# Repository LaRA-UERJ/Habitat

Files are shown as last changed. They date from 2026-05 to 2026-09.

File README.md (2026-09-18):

# Habitat

Open hardware designs for adaptive workspaces, modular workstations and experimental infrastructure for robotics and automation labs.

Developed by [LaRA](https://github.com/LaRA-UERJ) — Laboratório de Robótica e Automação, UERJ.

## Status

**Exploring.** This repository collects ideas, concepts, and references as options — no definitive design decisions yet. We're building understanding before committing to solutions.

## Philosophy

We're interested in workspaces as living systems — environments that adapt to people, tasks, and workflows, not the other way around. Key inspirations:

- **Robert Propst** — *The Office: A Facility Based on Change* (1968): workspaces should reconfigure as work changes
- **Bürolandschaft** — organic layouts based on information flow, not grids
- **OpenStructures** — interoperable modular grid systems
- **Open Source Ecology** — labs that build their own infrastructure
- **Cedric Price / Fun Palace** — fully reconfigurable spaces, nothing fixed

See [docs/concepts.md](docs/concepts.md) for a full catalog of philosophies presented as options.

## Active Projects

| Project | Description | Status |
|---|---|---|
| [Soldering Bench](designs/soldering-bench/) | Mobile standing bench for PCB soldering with pegboard, soldering iron, hot air, casters | Brief phase |
| [Workstation 120°](designs/workstation-120/) | Standing computer station with pegboard-mounted monitor, whiteboard, 120° angle, casters | Brief phase |
| [Partition 120°](designs/partition-120/) | Mobile 3-panel folding partition, steel frame, upholstered panels, acoustic + visual privacy, casters | Brief phase |
| [Break Pod](designs/break-pod/) | Mobile coffee and break station with countertop, open shelving, two counter stools, optional lower cabinet, casters | Brief phase |
| [Focus Pod](designs/focus-pod/) | Mobile semi-enclosed microenvironment for deep focus, calls, and silent work, with retractable L-desk, lounge chair, acoustic panels, casters | Brief phase |

## Design Principles Catalog

We're evaluating (not adopting) principles from multiple sources. See [docs/design-principles-catalog.md](docs/design-principles-catalog.md).

Highlights:
- 120° angles instead of 90°
- Postural variation (sit/stand/lean)
- Vertical surfaces as mental extension (pegboard, whiteboard)
- Gradual privacy (not binary open/closed)
- Task differentiation (different bench for different work)
- Radical adaptability (casters, modular frames, reconfigurable in hours)

## Modular Arrangements

All Habitat modules share the **120° principle**. This is not just a geometric preference — it enables modules to join into closed polygons, creating collective environments from individual, mobile pieces.

A module's edges are cut at 60° (half the 120° vertex angle), so when two modules meet at a corner, they form a clean 120° joint. This means any arrangement of modules at 120° closes naturally into a polygon.

### Hexagonal Focus Bay (6 modules)

The primary arrangement. Six modules at 120° form a hexagon — a semi-enclosed collective focus environment:

```
          ┌─────────────┐
         ╱               ╲
        ╱    Partition    ╲        ← Closure panel (acoustic + visual)
       ╱                   ╲
      │                     │
      │   Workstation 120°  │     ← Individual CAD/programming station
      │                     │
      │                     │
      │   Workstation 120°  │     ← Individual CAD/programming station
       ╲                   ╱
        ╲   Partition      ╱      ← Closure panel
         ╲               ╱
      ────┘             └────      ← Entrance (open, or low partition)
```

**Hybrid composition:**
- 2–3 sides: individual workstations (Workstation 120°) facing inward
- 2 sides: closure panels (Partition 120°) for acoustic and visual privacy
- 1 side: open entrance, or a low module (Break Pod, half-partition)

**Properties:**
- Creates a shared focus zone without walls or construction
- Each person has their own station but shares the enclosed environment
- Fully reconfigurable — disassemble and rearrange in minutes
- Naturally absorbs the 120° angle of each module — no custom joints needed
- Complementary to the Focus Pod: this is collective, the pod is individual

### Pentagon (5 modules, 108°)

Fewer modules, but requires module edges cut at 54° instead of 60° — a different geometry that doesn't align with the 120° principle. Explored as a concept (see reference images) but not the primary direction.

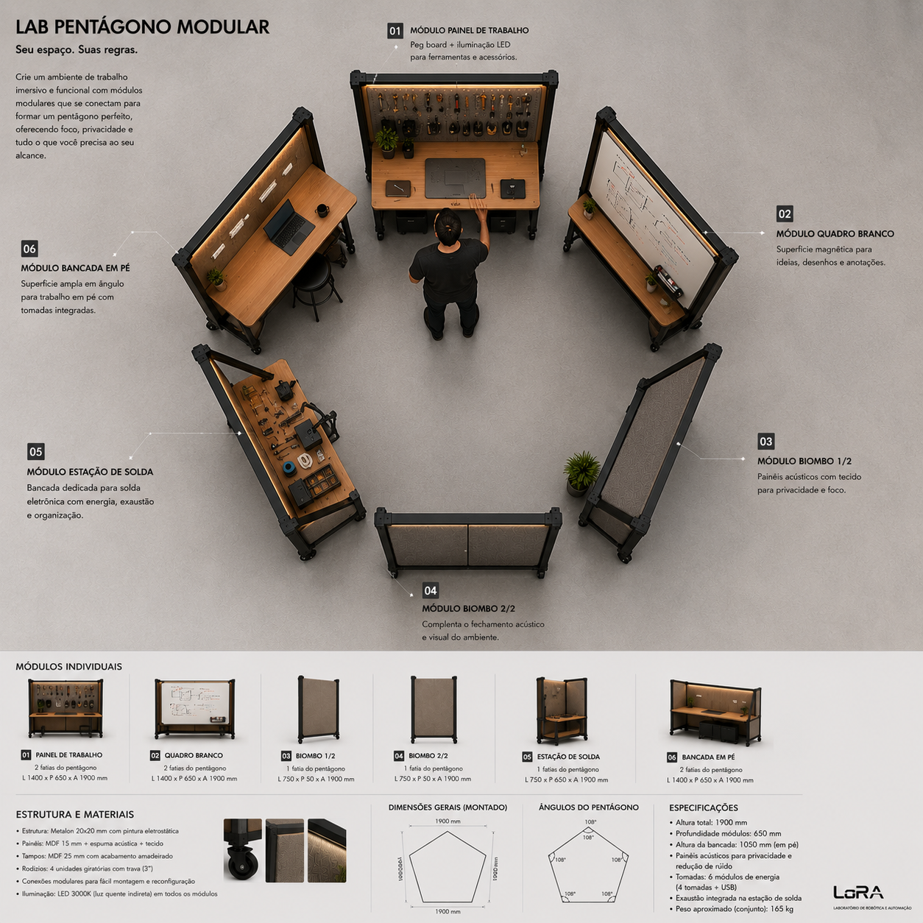
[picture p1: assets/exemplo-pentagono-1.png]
Pentagon arrangement concept 1


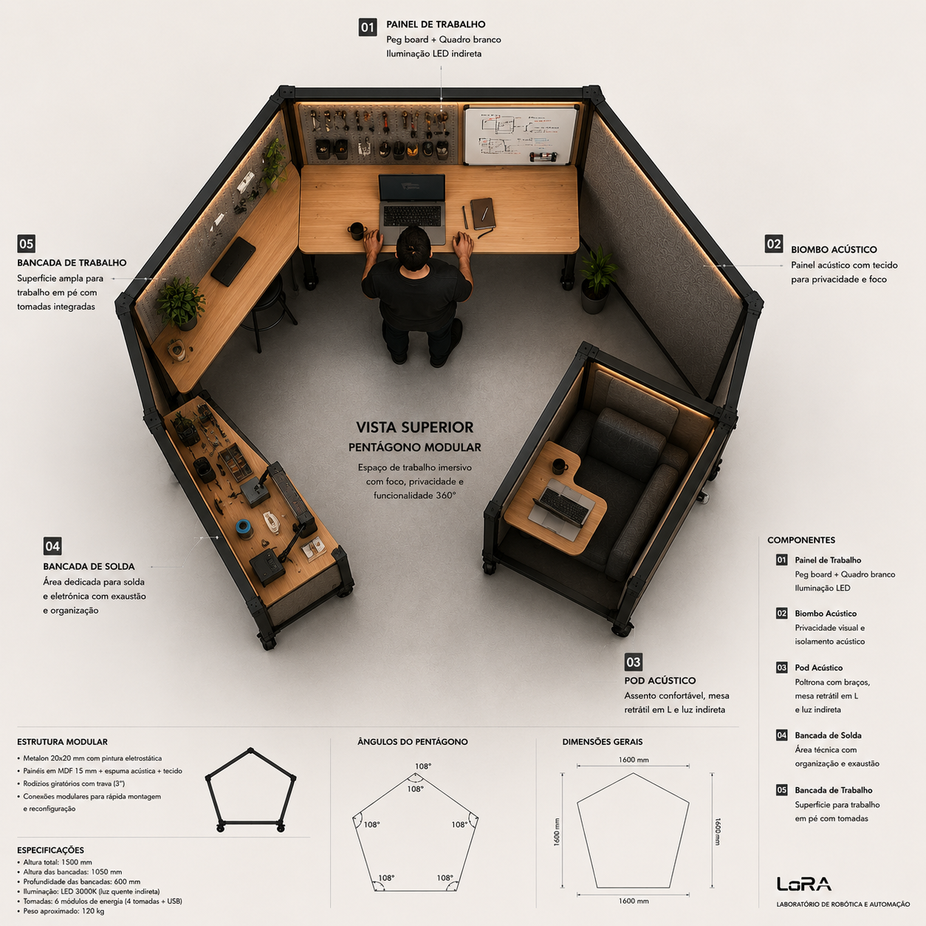
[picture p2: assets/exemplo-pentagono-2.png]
Pentagon arrangement concept 2


*Reference images illustrating the polygon arrangement concept. The images show pentagonal arrangements (108°) — the adopted direction is hexagonal (120°) to maintain alignment with the project's core geometry.*

### Module Roles in Arrangements

| Module | Role in Polygon | Notes |
|---|---|---|
| Workstation 120° | Active work side | Individual station facing inward |
| Partition 120° | Closure side | Acoustic + visual privacy |
| Break Pod | Entrance / social side | Low height, invites approach |
| Focus Pod | **Not part of arrangements** | Individual, separate, standalone |

### Implications for Module Design

For modules to join into polygons, each module needs:
- **Square-cut or 60°-cut edges** on the joining sides (exact approach TBD)
- **Consistent frame height** at the joint line so panels align
- **No protruding elements** (handles, casters, brackets) at the joint edges
- **Optional mechanical connection** — clips, magnets, or brackets to hold modules together

See [docs/layout-ideas.md](docs/layout-ideas.md) for detailed layout analysis.

**[Interactive Polygon Explorer →](https://lara-uerj.github.io/Habitat/tools/polygon-explorer.html)** — Adjust polygon, module size, bench depth, gaps, and person dimensions to visualize arrangements in scale.

## Layout Ideas

See [docs/layout-ideas.md](docs/layout-ideas.md) for spatial organization concepts, including a proposed layout for the LaRA 7×7m lab.

## References

All collected visual references, open-source projects, books, and videos: [docs/references.md](docs/references.md).

## Working in this repository

The CAD for the modules is generated by script, headless (FreeCAD + reportlab), not by
hand in a GUI. See:

- [AGENTS.md](AGENTS.md) — how to work here, house rules and module status
- [docs/cad-workflow.md](docs/cad-workflow.md) — the drawing pipeline and its pitfalls

## License

Hardware designs: **CERN-OHL-S v2** (Strongly Reciprocal) — see [LICENSE](LICENSE).

Documentation and text: **CC BY-SA 4.0**.

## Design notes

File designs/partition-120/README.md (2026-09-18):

# Partition 120°

Mobile 3-panel folding partition with upholstered panels for acoustic separation and visual privacy in the lab.

---

## Brief

A free-standing folding screen (biombo) with three panels joined at 120° angles. Steel frame (metalón) with locking casters, upholstered panels (wood + foam + fabric) for sound absorption. Designed to create semi-enclosed zones in the 7×7m LaRA lab — separating noisy tasks (mechanical, CNC) from quiet tasks (CAD, reading) while maintaining visual permeability and reconfigurability.

---

## Requirements

- **3 panels, 2 folds at 120°** — Each adjacent pair meets at 120°, forming a gentle arc (~240° total sweep) that partially encloses without closing off
- **Steel frame (metalón)** — Square tubing (likely 25×25 or 30×30), welded or bolted, painted matte black
- **Locking casters on feet** — Mobile by design; brakes engaged when positioned
- **Upholstered panels** — Plywood or MDF base + acoustic foam + fabric covering, attached to frame
- **Dual function** — Acoustic damping (reduces noise transfer between lab zones) + visual privacy (creates focus areas without full walls)
- **Foldable for storage** — Panels fold flat when not in use

---

## Design Options (Not Decided)

1. **Welded steel frame + piano hinges** — Continuous hinge along the full height of each joint. Strong, simple. Pros: rigid, clean. Cons: non-disassemblable, hinge must be sized for 120° stop.

2. **Bolted steel frame + pin hinges** — Frame members bolted together with removable pin hinges at the joints. Pros: disassembles for transport/storage. Cons: more hardware, potential play at joints.

3. **Aluminum extrusion frame (4040 profile)** — Modular, T-slot accessories, no welding needed. Pros: infinitely adjustable, lab can modify later. Cons: significantly more expensive than welded steel.

---

## Dimensions

Brief ranges, with what the CAD has settled so far. See [`cad/README.md`](cad/README.md)
for the full parameter table and the open decisions.

| Dimension | Brief range | Settled in CAD | Notes |
|---|---|---|---|
| Panel width | 80–100 cm | **900 mm** | Each of the 3 panels |
| Total height | 150–180 cm | **1706 mm** (1600 frame + 102 caster + 4 base plate) | Com o rodízio comercial de 102 mm |
| Panel thickness | 5–8 cm | **15 mm plywood** (foam + fabric open) | Cad passo 2: placa de compensado decorada; a espuma (30–50 mm) e o tecido seguem em aberto e não são desenhados |
| Frame tube | 25×25 or 30×30 mm | **30×30×1,5 mm** | Metalon quadrado — see Steel Frame Specs below |
| Caster diameter | 50–75 mm | **75 mm**, with brake | **4 units**, 2 per panel, only on the outer panels, inset 100 mm inside the panel plane |
| Base plate | — | **100 × 70 × 4 mm** welded under the bottom rail | 4 oblong slots 25 × 9 mm for the caster bolts |

Derived from the CAD: passo 1 (estrutura) 1358 × 1561 mm de planta, 14,64 m de tubo,
19,65 kg de aço. Passo 1b (base decidida): envoltória 1357,5 × 1560,9 × 1706 mm, 14,64 m de
tubo, 19,65 kg de tubo + 0,88 kg de chapas, 4 rodízios, margem de tombamento de 179,9 mm
(tomba a 11,62°; com 6 rodízios era 16,7°). Passo 2 (placa de compensado decorado, aprovado):
placa de 834 × 1534 × 15 mm com 3,0 mm de folga ao tubo, 12 cantoneiras 25 × 25 × 3 soldadas de
face e 12 parafusos de madeira Ø4 × 16, **55,32 kg** fabricados no total, painel de 11,51 kg por
folha, 13,8 kg por rodízio (limite 70 kg) e margem de tombamento de **175,0 mm (11,07°)**.

---

## Upholstered Panel Construction

| Layer | Material | Notes |
|---|---|---|
| Base | **Compensado decorado 15 mm**, 834 × 1534 mm | Decidido no CAD passo 2: 3 mm de folga ao tubo em todo o contorno |
| Foam | Espuma acústica 30–50 mm densidade média | **Em aberto** — não modelada nem desenhada |
| Fabric | Tecido acústico ou veludo | **Em aberto** — idem |
| Attachment | **12 cantoneiras em L 25 × 25 × 3 mm, soldadas de face na face interna dos montantes** (perna A 22,5 × 25 mm) + 4 parafusos de madeira Ø4 × 16 por folha, com a perna B deitada sobre a placa e o furo piloto Ø2,5 | O parafuso só é acionável na direção da normal do painel — é isso que decide a geometria da cantoneira. Ordem: soldar as abas, parafusar a placa nua, e só então colar espuma e grampear tecido |

---

## Steel Frame Specs

Espessuras de metalon típicas para mobiliário (dados de mercado):

| Aplicação | Bitola (gauge) | Espessura | Uso |
|---|---|---|---|
| Leve / budget | 18–22 ga | 0,75–1,2 mm | Móveis baratos, arquivos |
| Intermediário | 16 ga | ~1,5 mm | Mesas de escritório, móveis comerciais |
| Profissional / pesado | 14 ga | ~2,0 mm | Standing desks, setups multi-monitor |
| Industrial | 12 ga | ~2,65 mm | Bancadas pesadas, frames estruturais |

### Recomendação para o biombo

O biombo é alto (~160 cm), estreito, com painéis estofados — precisa de rigidez mas não suporta cargas pesadas como uma mesa.

| Componente | Espessura recomendada | Tubo | Racional |
|---|---|---|---|
| Colunas verticais | **1,5 mm (16 ga)** | 25×25 ou 30×30 mm | Suficiente para rigidez sem excesso de peso |
| Travessas horizontais | 1,2–1,5 mm | 25×25 mm | Menos solicitação que as colunas |
| Base / pés | 1,5–2,0 mm | 30×30 mm | Área de impacto (rodízios, batidas) |

**Sweet spot:** tubo 30×30 com 1,5 mm — leve para mover, rígido o suficiente para não balançar. Para mais robustez: 30×30 com 2,0 mm (14 ga).

### Fontes

- Eureka Ergonomic: "Steel Gauge Guide" — https://eurekaergonomic.com/blogs/eureka-ergonomic-blog/steel-gauge-guide-gaming-desk-frame-thickness
- Jianglin Steel: "Steel Tube for Furniture" — https://jlinsteel.com/steel-tube-for-furniture
- Prolamsa USA: Furniture tubing specs — https://www.prolamsausa.com/furniture/

---

## Hinge / Joint Design

The 120° angle between panels needs hinges that either:
- **Stop at 120°** — Hinge with built-in stop (custom bracket or welding limit)
- **Allow 120° but can fold flat** — Hinge permits 0°–180° range; position held by a detent, chain, or magnetic catch

Options:
- Dobradiça de piano (full-length) com batente soldado a 120°
- Dobradiça com pino removível (parafuso ou pino quick-release)
- Articulação tipo livro com limitador angular

---

## Reference Image

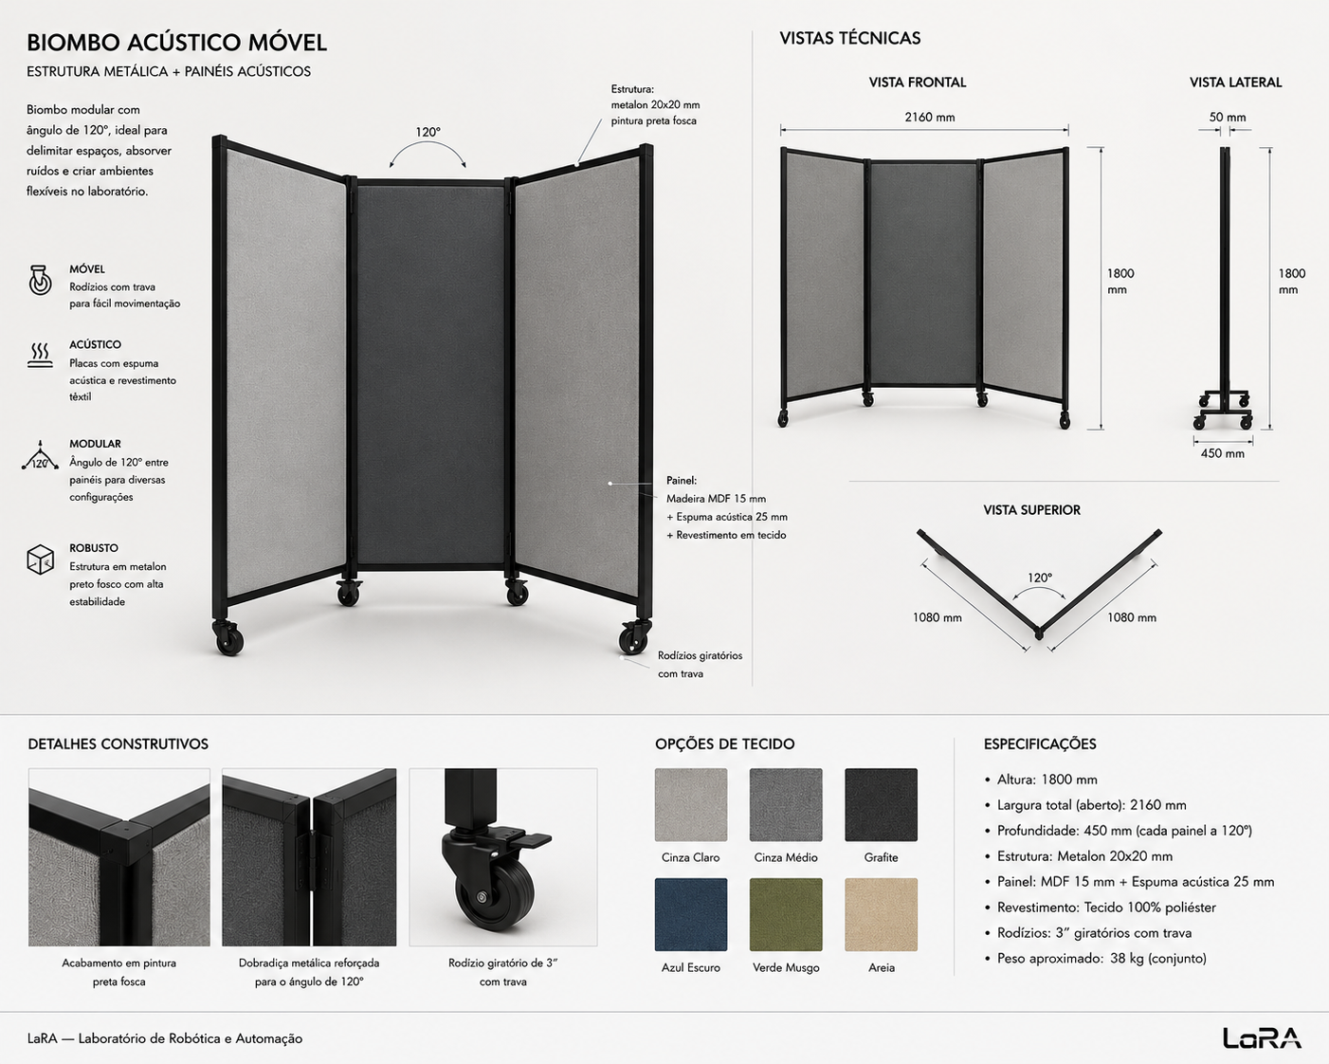
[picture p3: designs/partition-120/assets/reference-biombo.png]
Biombo reference — metal frame, upholstered panels, casters, 120° angles


*Three-panel folding partition: black metalón frame, locking casters, upholstered panels with wood + foam + fabric, 120° between panels.*

---

## Principles Being Evaluated

- [120° instead of 90°](../../docs/design-principles-catalog.md#120-instead-of-90) — Core geometry; avoids harsh corners and dead spaces
- [Gradual privacy](../../docs/design-principles-catalog.md#gradual-privacy-not-binary) — Medium privacy zone: blocks direct sightlines but preserves peripheral awareness
- [Everything on casters](../../docs/design-principles-catalog.md#everything-on-casters) — Mobile partitions reconfigure the lab in minutes
- [Noise gradient](../../docs/design-principles-catalog.md#noise-gradient) — Acoustic panels support the noise separation strategy between lab zones
- [Task differentiation](../../docs/concepts.md#1-robert-propst--the-office-a-facility-based-on-change-1968) — Partitions help define distinct activity zones within the same room

---

## Open Questions

- **Tecido:** qual material? Veludo acústico, camurça, lona? Precisa ser lavável e resistente em lab com 30+ estudantes
- **Dobradiças:** tipo piano contínua ou pino removível? Precisa de batente a 120° ou liberdade total?
- **Base:** resolvido — 4 rodízios, 2 por folha, só nas folhas das pontas, recuados 100 mm
  dentro do plano da folha (o pé em L foi descartado: risco de tropeço no lab)
- **Estabilidade / anti-capotamento:** resolvido — sem base alargada. Medido no modelo do passo
  2, com o painel dentro do CG: margem de tombamento de 175,0 mm (11,07°) com 4 rodízios; era
  179,9 mm (11,62°) sem o painel e 16,7° com 6 rodízios
- **Empilhável:** quando dobrado, pode ficar em pé encostado na parede? Precisa de suporte?
- **Acústica real:** quanta absorção o painel estofado realmente proporciona? Precisa de_teste ou dados de NRC (Noise Reduction Coefficient)?
- **Integração com bancadas:** o biombo pode servir como extensão da bancada de solda ou workstation 120°? Encaixa no sistema modular?
- **Cor do tecido:** escura (menos suja) ou clara (mais leve visualmente)? Padronizar ou permitir variação?
- **Painel de um lado só ou dos dois?** Estofado nos dois lados ou só no lado interno (lado do "fechamento")?
- **Peso total:** resolvido em parte — 55,32 kg medidos no CAD do passo 2 (tubo 19,652 +
  placa 34,543 + chapas 0,766 + cantoneiras 0,332 + parafusos 0,026), ainda sem o acabamento
  (espuma + tecido). Carga por rodízio 13,8 kg, contra limite de 70 kg/un

---

## CAD

Passo 1 (estrutura de metal) e passo 1b (base decidida: 4 rodízios comerciais), gerados por
script headless. Ver [`cad/README.md`](cad/README.md) para regenerar e para as pendências.

| Artefato | O que é |
|---|---|
| [`cad/saida/passo1_prancha.pdf`](cad/saida/passo1_prancha.pdf) | Prancha A3 cotada do passo 1 — estrutura |
| `cad/saida/passo1_biombo.step` | Sólido do passo 1 — **não versionado** (regenere com o script) |
| [`cad/saida/passo1_lista_corte.csv`](cad/saida/passo1_lista_corte.csv) | Lista de corte do passo 1 |
| [`cad/saida/passo1b_prancha.pdf`](cad/saida/passo1b_prancha.pdf) | **Prancha A3 do passo 1b** — frente perpendicular à folha central, lateral paralela às folhas das pontas, planta, isométrica e detalhe da base em 1:2 |
| `cad/saida/passo1b_prancha.dxf` | Geometria em mm para CAD — **não versionado** (regenere com o script) |
| `cad/saida/passo1b_biombo.step` | Sólido do passo 1b — **não versionado** (regenere com o script) |
| [`cad/saida/passo1b_lista_corte.csv`](cad/saida/passo1b_lista_corte.csv) | Lista de corte: tubo, chapa e rodízio |
| [`cad/saida/passo1b_render_iso.png`](cad/saida/passo1b_render_iso.png) | Render 3D isométrico |
| [`cad/saida/passo1b_render_persp.png`](cad/saida/passo1b_render_persp.png) | Render 3D em perspectiva |
| [`cad/saida/passo1b_render_close.png`](cad/saida/passo1b_render_close.png) | Render 3D do close na base |
| [`cad/saida/passo2_prancha.pdf`](cad/saida/passo2_prancha.pdf) | **Prancha A3 do passo 2** — 4 vistas em cima; embaixo a placa decorada 1:20, a lista de material e as notas de fixação e montagem |
| `cad/saida/passo2_prancha.dxf` / `passo2_biombo.step` | Geometria em mm e sólido do passo 2 (67 peças) — **não versionados** |
| [`cad/saida/passo2_lista_corte.csv`](cad/saida/passo2_lista_corte.csv) | Lista de corte: tubo, chapa, cantoneiras e placa |
| [`cad/saida/passo2_lista_compras.csv`](cad/saida/passo2_lista_compras.csv) | Lista de compras: compensado, parafusos e o acabamento opcional |
| [`cad/saida/passo2_render_iso.png`](cad/saida/passo2_render_iso.png) | Render 3D isométrico do conjunto com o painel |
| [`cad/saida/passo2_render_persp.png`](cad/saida/passo2_render_persp.png) | Render 3D em perspectiva |
| [`cad/saida/passo2_render_close.png`](cad/saida/passo2_render_close.png) | Render 3D do close em **uma fixação** (cantoneira + parafuso + placa) |

O que já está fechado: metalon 30×30×1,5 mm, folha de 900 × 1600 mm, 120° internos entre
folhas (giro de 60° por junta), rodízio moveleiro Ø75 com freio de altura 102 mm e carga
70 kg, **4 rodízios** (2 por folha, só nas folhas das pontas, recuados 100 mm dentro do plano
da folha), chapa soldada 100 × 70 × 4 mm com 4 rasgos oblongos sob cada rodízio, altura total
1706 mm, 14,64 m de tubo e, no passo 2, **placa de compensado decorada 15 mm de 834 × 1534 mm**
com 3 mm de folga ao tubo, fixada por **12 cantoneiras 25 × 25 × 3 mm soldadas de face** na face
interna dos montantes com parafuso de madeira Ø4 × 16 (furo piloto Ø2,5). Massa fabricada
55,32 kg e margem de tombamento 175,0 mm (11,07°).

O que ainda não existe: o acabamento do painel (espuma e tecido — como e se existem), as
dobradiças, e a confirmação do passo entre os furos da chapa (medir o rodízio comprado antes
de furar). Ver [`cad/README.md`](cad/README.md#pendências).

## Files

| Path | Description |
|---|---|
| `cad/` | Script de geração + `saida/` com prancha, lista de corte, relatório e renders (DXF/STEP saem do script, não versionados) |
| `assets/reference-biombo.png` | Reference image of the partition concept |

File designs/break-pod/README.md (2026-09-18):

# Break Pod

Mobile coffee and break module for shared lab spaces. A compact, self-contained station that provides a ritual pause point — coffee, conversation, and informal collaboration — without requiring permanent infrastructure or plumbing.

---

## Brief

A free-standing, mobile break station inspired by coffee carts, kitchen islands, and micro-bars. The concept combines a countertop for a coffee machine, open shelving for cups and supplies, optional lower cabinet storage, and two stools — all on locking casters for reconfigurable lab architecture. The break pod is not just about coffee; it's about creating a intentional pause point in the workspace, a social node that encourages informal exchange and mental reset.

### Use Cases

- Coffee and tea preparation
- Informal conversations and quick syncs
- Mental reset between deep work sessions
- Hosting visitors with a coffee
- Water cooler moments in a lab context
- Snack and refreshment station

### Sensation

The pod should transmit:

- Warmth
- Informality
- Hospitality
- Shared ownership
- Pause / respite

A "casulo de pausa" — a coffee break cockpit, a social anchor in the lab.

---

## Requirements

- **Countertop surface** — Dedicated space for a coffee machine (espresso, drip, or pod-based), with enough depth for the machine + cups + preparation area
- **Open shelving** — At least one shelf above or behind the counter for cups, coffee, sugar, tea, and supplies. Visible and accessible — the supplies are part of the aesthetic, not hidden away
- **Two stools** — Compact counter-height stools (or stools that store under/around the pod) for sitting and chatting
- **Mobile (locking casters)** — Industrial black swivel casters with brakes. Same mobility language as the other pods
- **Optional lower cabinet** — Enclosed storage below the counter for bulk supplies, cleaning, waste bin. To be decided if included or kept minimal
- **Industrial clean aesthetic** — Consistent with the lab language: black matte steel frame, warm wood or laminate countertop, minimal hardware

---

## Design Options (Not Decided)

### Chassis

1. **Welded metalon frame** — 30×30 mm steel tubing, welded joints. Maximum rigidity, cleanest look. Non-disassemblable.
2. **Bolted metalon frame** — 30×30 mm tubing with bolted corner brackets. Disassembles for transport, no welding needed.
3. **Mixed frame (20×20 + 30×30)** — 30×30 for columns and base, 20×20 for shelf frames and secondary structure. Weight savings where possible.

### Lower Storage

1. **Open shelf** — Simple lower shelf, fully visible. Minimal, light, easy to build. No doors or drawers.
2. **Enclosed cabinet** — Doors (MDF or plywood) with magnetic catches. Hides clutter, stores bulk supplies and waste bin.
3. **Hybrid** — One side open shelf, one side cabinet. Best of both but more complex.
4. **No lower storage** — Countertop and upper shelf only, maximum visual lightness. Supplies stored elsewhere.

### Countertop

1. **Solid wood (hardwood)** — Warm, tactile, ages beautifully. Requires finishing (oil or varnish). Heavier.
2. **Plywood with hardwood edge** — Birch or pine plywood, exposed edge banding. Lab aesthetic, lighter, cheaper.
3. **Laminate (Formica)** — Durable, waterproof, easy to clean. Less character, more practical.
4. **Stainless steel** — Industrial kitchen aesthetic, ultra-durable, waterproof. Cold aesthetic but very practical for spills.

### Shelving

1. **Upper open shelf (fixed)** — Single shelf above/behind the counter. Simple, permanent.
2. **Multiple narrow shelves** — Stacked shelves at different heights for cups, supplies, decoration.
3. **Pegboard back panel** — Metalon + pegboard or slatwall behind counter. Hooks for cups, accessories. Consistent with other lab projects.
4. **Side shelf / wing** — Additional narrow surface extending to one side, for extra prep space or decoration.

---

## Dimensions (TBD)

| Dimension | Range | Notes |
|---|---|---|
| Overall width | 100–130 cm | Machine + shelf + prep area + stool clearance on sides |
| Overall depth | 50–65 cm | Counter depth, enough for machine + cups in front |
| Overall height | 90–110 cm | Counter height (~90 cm) + upper shelf or backsplash |
| Counter height | ~90 cm | Standard counter / bar height |
| Counter depth | ~50–60 cm | Machine depth + cup space |
| Upper shelf height | ~15–25 cm above counter | Accessible, not too high |
| Stool seat height | ~65 cm | Counter-height stool |

---

## Steel Frame Specs

| Component | Recommended | Tube | Rationale |
|---|---|---|---|
| Main columns | 1,5–2,0 mm | 30×30 mm | Primary structural members, support counter + machine + supplies |
| Base frame | 1,5–2,0 mm | 30×30 mm | Caster mounting points, stability base |
| Shelf frames | 1,0–1,5 mm | 20×20 mm | Lighter secondary structure for shelving |
| Counter support | 1,5 mm | 30×30 mm | Supports countertop + dynamic load (machine + water) |

**Finish:** Pintura eletrostática preta fosca microtexturizada (consistent with other pods)

---

## Stools

| Feature | Spec |
|---|---|
| Quantity | 2 |
| Style | Compact counter stool, industrial or minimalist |
| Seat height | ~65 cm |
| Material | Steel frame + wood seat, or all-steel |
| Storage | Can tuck against or under the pod when not in use |
| Integration | To be decided — integrated into frame or freestanding |

---

## Mobility

| Feature | Spec |
|---|---|
| Caster type | Industrial, black, swivel, with brake |
| Quantity | 4 (one per corner of base frame) |
| Diameter | 50–75 mm |
| Purpose | Pod moves to where it's needed — near workstations, in a corner, or against a wall |

---

## Optional Extras

### Water & Waste

- Galão de água embutido (5–10L) — gravity-fed or small pump
- Sistema de água ligado à rede (se posição fixa)
- Coletor de gotejamento / drip tray
- Lixeira embutida no armário inferior

### Electrical

- Tomada AC para máquina de café (110/220V)
- USB-C PD charging para celular enquanto toma café
- Iluminação indireta sob a prateleira (LED warm, 2700–3000K)

### Social

- Quadro negro / chalkboard em um dos lados para recados e mensagens
- Suporte para planta ou decoração
- Hook para aventais ou toalhas

---

## Reference Image

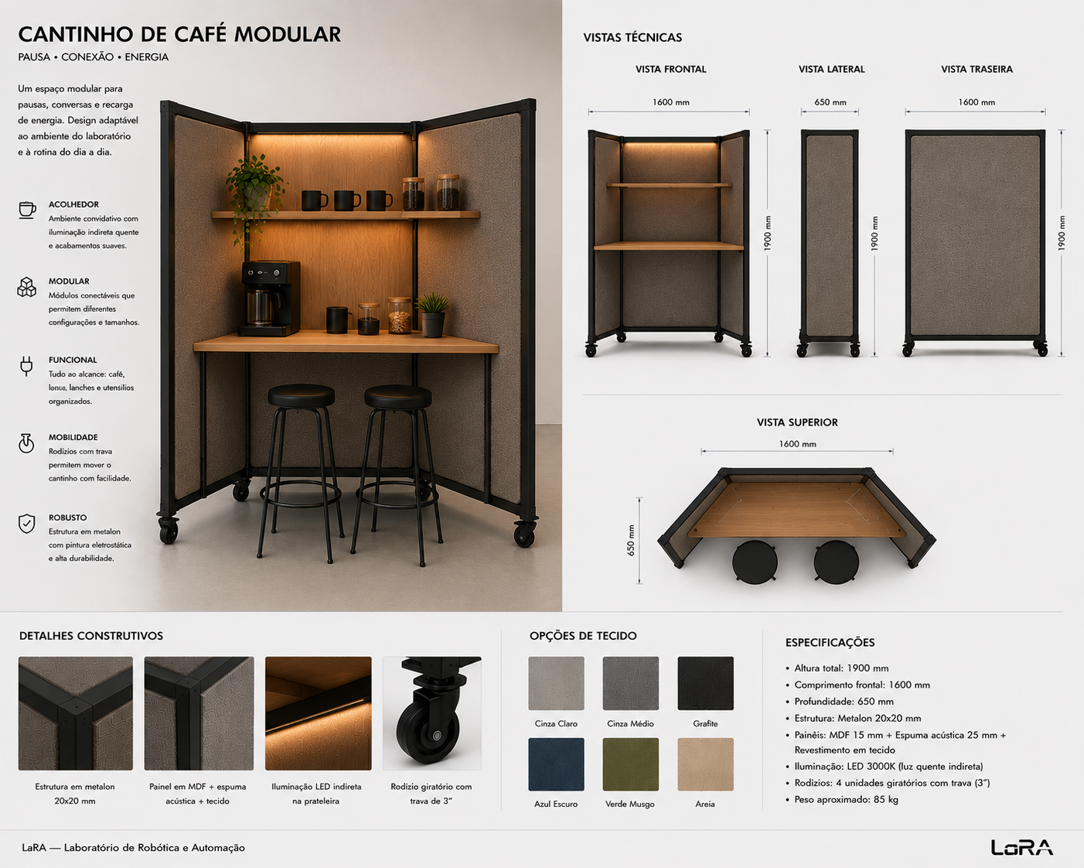
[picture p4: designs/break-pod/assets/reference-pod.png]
Break Pod reference — mobile coffee station with countertop, shelving, and stools


*Mobile break/coffee module with countertop for coffee machine, open shelving, two counter stools, and industrial casters.*

---

## Principles Being Evaluated

- [Everything on casters](../../docs/design-principles-catalog.md#everything-on-casters) — Mobile social infrastructure, reconfigurable in minutes
- [Task differentiation](../../docs/concepts.md#1-robert-propst--the-office-a-facility-based-on-change-1968) — A dedicated station for breaks, distinct from work zones
- [Walls as mental extension](../../docs/design-principles-catalog.md#walls-as-mental-extension) — Shelving and pegboard display supplies as part of the aesthetic
- [Gradual privacy](../../docs/design-principles-catalog.md#gradual-privacy-not-binary) — Semi-open, social posture — the opposite of the Focus Pod, a complementary social node
- [Postural variation](../../docs/design-principles-catalog.md#postural-variation) — Standing at counter + perched on stools — a break from seated work

---

## Name Candidates

Working names within the LaRA universe:

- **LaRA Break Pod**
- **LaRA Coffee Pod**
- **LaRA Brew Cart**
- **LaRA Pause Station**
- **LaRA Social Node**
- **LaRA Café Module**
- **LaRA Refuel Pod**

---

## Open Questions

- **Lower cabinet:** Enclosed storage, open shelf, or nothing at all?
- **Coffee machine:** Specific machine in mind? Dimensions and power requirements affect the design
- **Water supply:** Gravity-fed galão, plumbed, or manual fill?
- **Waste:** Integrated bin or separate?
- **Stools:** Integrated into frame or freestanding? Fixed or foldable?
- **Width:** Minimum viable width that feels comfortable for two people?
- **Countertop material:** Wood (warm) vs laminate (practical) vs steel (industrial)?
- **Pegboard:** Worth adding for cup hooks and accessory display?
- **Integration with other projects:** Share casters, frame joints, panel construction with Focus Pod and Partition 120°?
- **Position in lab:** Against wall or freestanding? Affects back panel design
- **Supplies capacity:** How many cups, how much coffee? Determines shelf sizing

---

## Files

| Path | Description |
|---|---|
| `cad/` | CAD files (.step, .FCStd) — to be added |
| `assets/reference-pod.png` | Reference image of the break pod concept |

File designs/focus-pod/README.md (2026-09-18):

# Focus Pod

Mobile microenvironment for deep focus, calls, reading, and silent work. A semi-enclosed capsule that provides psychological comfort, partial isolation, and an industrial-lab aesthetic — without feeling like a corporate booth.

---

## Brief

A free-standing, mobile individual pod inspired by acoustic pods, reading nooks, Scandinavian booths, and micro-architecture. The concept combines comfort, acoustic damping, indirect lighting, a retractable L-shaped desk, and an integrated lounge chair — all on locking casters for reconfigurable lab architecture.

### Use Cases

- Deep coding / programming
- Video calls and meetings
- Reading datasheets and papers
- Quick rest / mental reset
- Brainstorming and sketching
- Silent concentrated work
- Personal retreat in a shared lab

### Sensation

The pod should transmit:

- Security
- Concentration
- Warmth
- Silence
- Introspection

Almost a "casulo de engenharia" — a human cockpit, a focus capsule.

---

## Requirements

- **Semi-enclosed format** — High side panels, partial ceiling, open front. Avoids claustrophobia, excessive heat, and "box" feeling while maintaining privacy and psychological protection
- **Mobile (locking casters)** — Industrial black swivel casters with brakes. Pod is reconfigurable architecture, not fixed furniture
- **Acoustic panels** — Layered construction: structural MDF + acoustic foam + optional acoustic blanket + tensioned fabric (30–50 mm total thickness)
- **Integrated lounge chair** — Armrests on both sides, dense foam, slightly reclined backrest, comfortable depth. Compact "mini cockpit" style
- **Retractable L-shaped desk** — Stores vertically against the side panel, opens forward when needed. Asymmetric L: wider outer section (notebook + mouse + coffee), narrower rear section (avoids hitting chair arm)
- **Indirect warm lighting** — Embedded LED strip (2700–3000K), hidden behind profile, with optional dimmer and presence sensor
- **Industrial clean aesthetic** — Black matte microtextured electrostatic paint on steel frame, warm fabric panels

---

## Design Options (Not Decided)

### Chassis

1. **Welded metalon frame** — 30×30 mm steel tubing, welded joints, maximum rigidity. Pros: strongest, cleanest welds. Cons: non-disassemblable, needs welding equipment.
2. **Bolted metalon frame** — 30×30 mm tubing with bolted corner brackets. Pros: disassembles for transport, no welding needed. Cons: more hardware visible, potential play at joints.
3. **Mixed frame (20×20 + 30×30)** — 30×30 for main structural members (columns, base), 20×20 for panel frames and ceiling structure. Pros: weight savings where less strength is needed. Cons: two tube sizes to source.

### Retractable Desk Mechanism

1. **Reinforced hinge + gas strut** — Desk folds down on heavy-duty hinge, gas strut (like car trunk lift) holds it open and controls closing speed. Pros: smooth, controlled motion. Cons: gas strut sizing critical.
2. **Articulated rail** — Desk slides and pivots on a rail system. Pros: compact storage, varied positions. Cons: more complex, potential play.
3. **Simple hinge + magnetic catch** — Basic hinge with magnetic lock in stored (vertical) position. Pros: simplest, cheapest. Cons: no damping on close, relies on user care.
4. **Scissor mechanism** — Desk folds in an X-pattern. Pros: very compact storage. Cons: complex, harder to build.

---

## Dimensions (TBD)

| Dimension | Range | Notes |
|---|---|---|
| Overall width | 90–110 cm | Wide enough for chair + desk, narrow enough for lab aisle |
| Overall depth | 80–100 cm | Chair depth + desk depth + clearance |
| Overall height | 180–200 cm | Above standing eye level, below ceiling (~280 cm) |
| Partial ceiling depth | 40–60 cm | Overhang at top — enough to mount light, not enough to feel enclosed |
| Panel height | 130–160 cm | Blocks sightlines when seated |
| Desk surface (outer) | 50–60 cm wide × 35–40 cm deep | Notebook + mouse + coffee |
| Desk surface (rear) | 25–30 cm wide × 20–25 cm deep | Narrow wing — avoids chair arm |
| Desk height | ~70–75 cm | Standard seated desk height |
| Chair seat height | ~42–45 cm | Lounge chair comfort |

---

## Steel Frame Specs

| Component | Recommended | Tube | Rationale |
|---|---|---|---|
| Main columns | 1,5–2,0 mm | 30×30 mm | Primary structural members, support chair + desk + person |
| Base frame | 1,5–2,0 mm | 30×30 mm | Caster mounting points, impact area |
| Panel frames | 1,0–1,5 mm | 20×20 mm | Lighter secondary structure for panel mounting |
| Ceiling structure | 1,0–1,2 mm | 20×20 mm | Minimal load, weight savings |
| Desk mount | 2,0 mm | 30×30 mm | Dynamic load from typing, leaning |

**Finish:** Pintura eletrostática preta fosca microtexturizada

---

## Panel Construction

| Layer | Material | Notes |
|---|---|---|
| Structural base | MDF 12–15 mm | Rigid panel substrate |
| Acoustic foam | Espuma acústica 15–25 mm | Medium density, sound absorption |
| Acoustic blanket (optional) | Manta acústica (lã PET reciclada ou melamina) | Additional absorption + thermal insulation |
| Outer fabric | Tecido tensionado (feltro, poliéster acústico, boucle, linho sintético) | Stretched and stapled or clipped to MDF |
| Total thickness | 30–50 mm | |

### Fabric Options

| Type | Character | Durability |
|---|---|---|
| Feltro premium | Warm, acoustic, matte | High |
| Poliéster acústico | Technical, clean | Very high |
| Boucle técnico | Textured, contemporary | Medium-high |
| Linho sintético | Light, elegant | Medium |

### Color Palette

- Grafite (dark gray)
- Areia (sand)
- Verde musgo (moss green)
- Azul petróleo (petrol blue)
- Cinza quente (warm gray)

---

## Retractable L-Shaped Desk

The desk is the most interesting mechanical element of the pod.

### Concept

- Stores vertically against the inner side panel
- Opens forward (rotates down) when needed
- Asymmetric L-shape:

```
        ┌──────────────┐  ← outer section (wider)
        │              │     notebook, mouse, coffee, tablet
        │              │
        ├──────┐       │
        │ rear │       │  ← rear section (narrower)
        │      │       │     avoids chair arm, ergonomic clearance
        └──────┴───────┘
```

### Mechanism Options

| Mechanism | Pros | Cons |
|---|---|---|
| Dobradiça reforçada + pistão a gás | Smooth motion, controlled close | Piston sizing critical |
| Trilho articulado | Compact, varied positions | Complex, potential play |
| Dobradiça simples + trava magnética | Simplest, cheapest | No damping |
| Mecanismo tesoura | Very compact storage | Complex build |

---

## Lounge Chair

| Feature | Spec |
|---|---|
| Style | Compact lounge / reading chair / "mini cockpit" |
| Armrests | Both sides |
| Foam | High density |
| Backrest | Slightly reclined (~105–110°) |
| Seat depth | Comfortable for extended sessions |
| Upholstery | Same fabric family as panels (visual coherence) |

---

## Lighting

| Feature | Spec |
|---|---|
| Type | Fita LED embutida (indirect) |
| Color temperature | 2700–3000K (warm) |
| Mounting | Hidden behind aluminum profile or panel edge |
| Control | Dimmer (rotary or touch) |
| Optional | Sensor de presença (auto on/off) |
| Optional | USB-C integrated in light profile |

---

## Mobility

| Feature | Spec |
|---|---|
| Caster type | Industrial, black, swivel, with brake |
| Quantity | 4 (one per corner of base frame) |
| Diameter | 50–75 mm |
| Purpose | Reconfigurable lab architecture — pod moves as needs change |

---

## Optional Extras

### Electrical

- Tomadas AC (110/220V)
- USB-C PD charging
- Carregador wireless embutido na mesa
- Iluminação RGB indireta (mood)

### Acoustic Upgrades

- Lã PET reciclada (eco-friendly acoustic absorption)
- Espuma melamínica (fire-retardant)
- Difusores acústicos internos (break up standing waves)

### Smart / IoT

- ESP32 or similar microcontroller
- Sensores mmWave (presence detection, more reliable than PIR)
- Home Assistant integration
- Sensors: presença, luminosidade, qualidade do ar (CO₂, VOC), temperatura, umidade
- Automated lighting and ventilation based on occupancy

---

## Reference Image

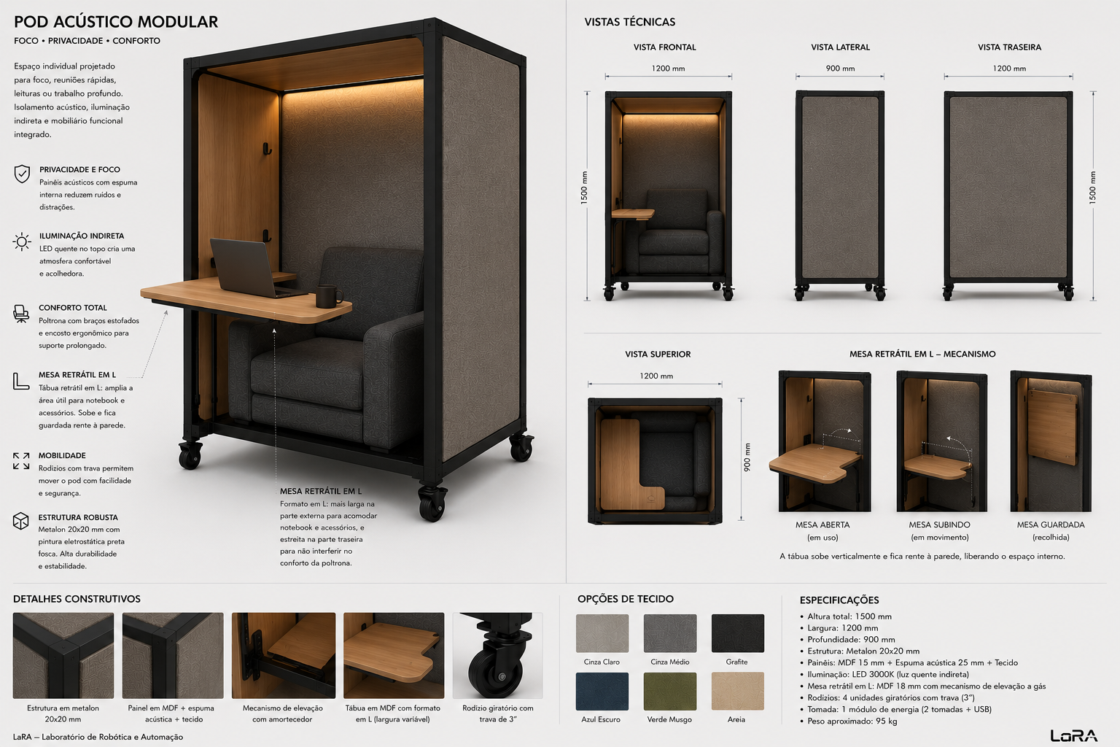
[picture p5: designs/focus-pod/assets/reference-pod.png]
Focus Pod reference — semi-enclosed capsule, metal frame, upholstered panels, integrated chair, retractable desk


*Semi-enclosed mobile focus pod with acoustic panels, lounge chair, retractable L-desk, indirect lighting, and industrial casters.*

---

## Principles Being Evaluated

- [Gradual privacy](../../docs/design-principles-catalog.md#gradual-privacy-not-binary) — High privacy zone: deep focus and calls, semi-enclosed but not claustrophobic
- [Everything on casters](../../docs/design-principles-catalog.md#everything-on-casters) — Mobile architecture, reconfigurable in minutes
- [Noise gradient](../../docs/design-principles-catalog.md#noise-gradient) — Acoustic isolation for the quietest zone in the lab
- [Postural variation](../../docs/design-principles-catalog.md#postural-variation) — Lounge seating + desk surface = comfortable alternation
- [Task differentiation](../../docs/concepts.md#1-robert-propst--the-office-a-facility-based-on-change-1968) — A dedicated space for focused individual work, distinct from collaborative benches
- [Walls as mental extension](../../docs/design-principles-catalog.md#walls-as-mental-extension) — Panels define territory and reduce visual noise

---

## Name Candidates

Working names within the LaRA universe:

- **LaRA Focus Pod**
- **LaRA Nest**
- **LaRA Capsule**
- **LaRA Refuge**
- **LaRA Cocoon**
- **LaRA Booth**
- **LaRA Node**
- **LaRA QuietCell**
- **LaRA Deep Work Pod**

---

## Open Questions

- **Dimensions:** Final width/depth/height — needs to fit through standard doors (~80 cm) if moved between rooms?
- **Weight:** With metalon + MDF + foam + fabric + chair + casters — manageable by 1-2 people?
- **Stability:** High and narrow — anti-tip measures? Wider base than top? Weighted bottom?
- **Cost estimate:** Total BOM for one pod — viable for a university lab budget?
- **Fabricability:** Can the lab build this with available tools (welding, CNC, hand tools)?
- **Chair:** Off-the-shelf compact lounge chair modified to integrate, or custom upholstery from scratch?
- **Desk mechanism:** Which retractable mechanism to prototype first? Gas strut seems most promising
- **Ventilation:** Semi-enclosed with partial ceiling — does it need active ventilation for long sessions?
- **Panel attachment:** How do panels connect to the frame? Screws from inside? Quick-release clips?
- **Disassembly:** Should the pod be fully flat-packable or is semi-permanent assembly acceptable?
- **Acoustic performance:** Real NRC target? How much isolation is needed to make calls without disturbing others?
- **Name:** Which name to adopt?
- **Integration with other projects:** Can the pod share components (casters, panels, frame joints) with the Partition 120° and Workstation 120°?

---

## Files

| Path | Description |
|---|---|
| `cad/` | CAD files (.step, .FCStd) — to be added |
| `assets/reference-pod.png` | Reference image of the pod concept |

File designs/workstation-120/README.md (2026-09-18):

# Workstation 120°

Standing/sitting computer station with pegboard-mounted monitor, whiteboard, and 120° angle, on casters.

---

## Brief

A modular workstation for CAD, programming, and documentation work. The key feature is a 120° angle between the computer surface and an adjacent whiteboard, creating a semi-enclosed "bay" that supports both screen work and spontaneous sketching/diagramming.

### Requirements

- **120° angle** — Between the computer desk surface and the whiteboard panel, forming a natural work bay
- **Monitor mounted on pegboard** — Monitor arm or VESA mount attached to a pegboard panel (not the desk), keeping the desk surface clear
- **Whiteboard panel** — Adjacent surface at 120° for sketching circuits, diagrams, equations, planning
- **Casters on feet** — Mobile station that can be repositioned in the lab
- **Keyboard/mouse surface** — At desk height (~72-75 cm seated, or adjustable)
- **Chair-compatible** — Allow both standing and seated use (adjustable height or stool option)

### Design Options (Not Decided)

1. **Aluminum extrusion frame with 120° bracket** — Two profile sections meeting at 120° with a custom bracket. Pegboard on one side, whiteboard on the other. Monitor arm on T-slot. Pros: clean, adjustable, industrial. Cons: custom bracket complexity.
2. **Plywood panels with CNC-cut 120° joint** — Two plywood panels joined at 120° with a finger joint or bracket cut on CNC. Lighter, warmer. Pros: lab can fabricate it. Cons: less adjustable once built.
3. **Separate modules** — Desk module + whiteboard module + pegboard module, each independent, connected at 120° via a shared base. Pros: can separate into individual units. Cons: alignment and rigidity.

### Dimensions (TBD)

- Total width (both wings): ~150–180 cm (across the 120° V)
- Computer desk depth: ~60–70 cm
- Whiteboard height: ~90–120 cm
- Overall height: ~120–150 cm (pegboard above desk level)
- Footprint: ~120 cm deep × 150 cm wide (projected)

### Equipment Integration

| Equipment | Mounting | Notes |
|---|---|---|
| Monitor (24-27") | Pegboard VESA mount or arm | Off the desk surface |
| Keyboard + mouse | Desk surface or tray | Pull-out tray saves space |
| Laptop (if used) | Desk surface or stand | Alternative to desktop monitor |
| Whiteboard | Panel at 120° | Magnetic whiteboard — markers + eraser nearby |
| Pegboard | Behind/above monitor | Small shelves, hooks for accessories |
| Task light | Pegboard or overhead | Adjustable arm, avoids monitor glare |
| Power | Under-desk power strip | For laptop/monitor/charger |
| Cable management | Along frame or under desk | Important for mobile station |

### 120° Angle Rationale

From [Propst's principles](../../docs/design-principles-catalog.md#120-instead-of-90):
- 120° creates a partial enclosure without feeling confined
- Preserves peripheral vision — awareness of the lab
- Natural entry/exit flow — not backing into a corner
- Two surfaces (screen + whiteboard) visible with a head turn, not a walk
- Better for collaborative pair work than a flat desk against a wall

### Reference Images

### Concept Render

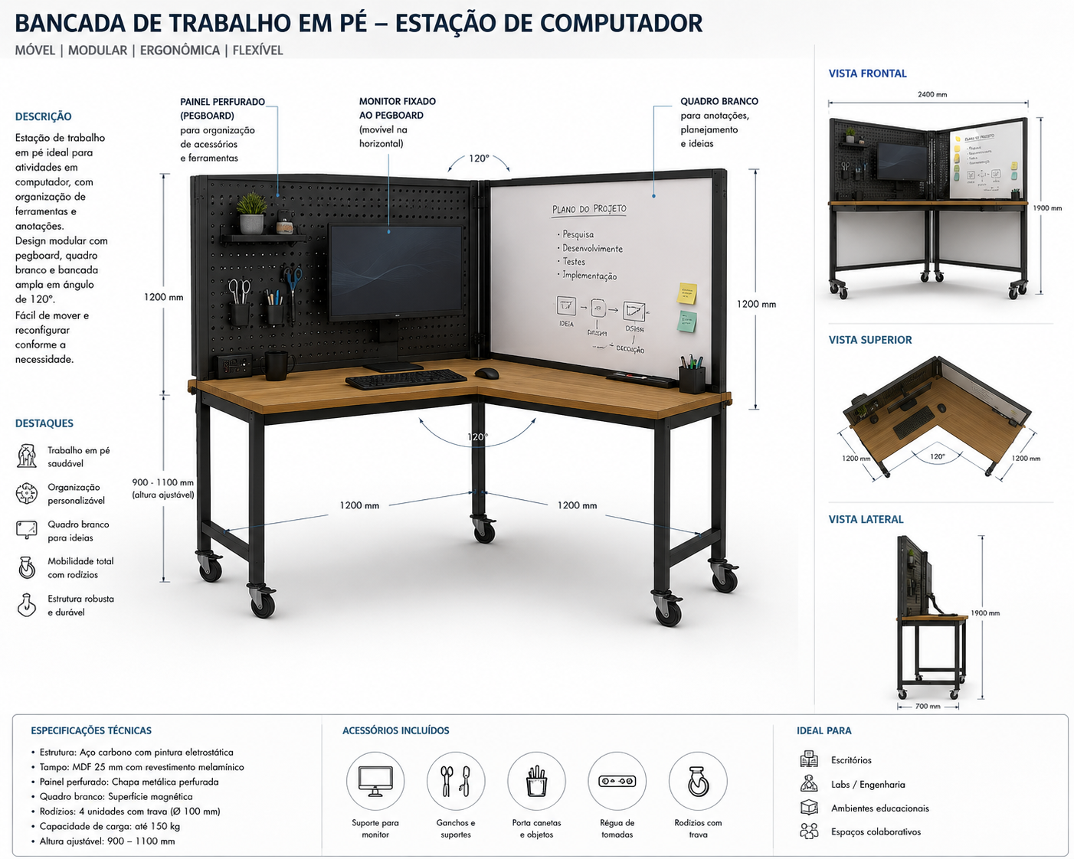
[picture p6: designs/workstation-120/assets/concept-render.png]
Workstation 120° concept


*Standing computer station at 120° with pegboard-mounted monitor, whiteboard panel, and casters.*

### Principles Being Evaluated

- [120° instead of 90°](../../docs/design-principles-catalog.md#120-instead-of-90) — Core design feature
- [Vertical surfaces as mental extension](../../docs/design-principles-catalog.md#walls-as-mental-extension) — Whiteboard as working memory
- [Postural variation](../../docs/design-principles-catalog.md#postural-variation) — Should support both sitting and standing
- [Everything on casters](../../docs/design-principles-catalog.md#everything-on-casters) — Mobile by requirement
- [Gradual privacy](../../docs/design-principles-catalog.md#gradual-privacy-not-binary) — 120° bay provides medium privacy for focused CAD work

### Open Questions

- Adjustable height (sit/stand): linear actuator, manual pin-lock, or fixed compromise height?
- How to keep the whiteboard clean in a shared environment (markers walk away)
- Storage: where do keyboard, mouse, laptop go when not in use?
- If two of these are placed facing each other, does the 120° create a good collaboration bay?
- Weight: monitor + whiteboard + pegboard can be top-heavy — stability concern with casters

---

## Files

| Path | Description |
|---|---|
| `cad/` | CAD files (.step, .FCStd) — to be added |
| `assets/` | Imagens de referência e renders |

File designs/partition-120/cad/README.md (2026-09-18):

# CAD do Biombo 120 (Partition 120)

Geração headless, por script. Leia [docs/cad-workflow.md](../../../docs/cad-workflow.md)
antes de mexer.

## Regenerar

```bash
cd <raiz do repo>
freecadcmd designs/partition-120/cad/biombo_passo1.py      # passo 1: estrutura
freecadcmd designs/partition-120/cad/biombo_passo1b.py     # passo 1b: base decidida
freecadcmd designs/partition-120/cad/biombo_passo2.py      # passo 2: placa e fixacao

# render 3D em PNG (FreeCAD GUI num X virtual: nao abre janela na sua tela)
RENDER_FCSTD=$PWD/designs/partition-120/cad/saida/passo1b_biombo.FCStd \
RENDER_NOME=passo1b_render \
  xvfb-run -a freecad $PWD/scripts/render_3d.py

# passo 2: o close e' em UMA fixacao (aba + parafuso + cabeca), nao no rodizio
RENDER_FCSTD=$PWD/designs/partition-120/cad/saida/passo2_biombo.FCStd \
RENDER_NOME=passo2_render RENDER_CLOSE=folha1_a_aba \
  xvfb-run -a freecad $PWD/scripts/render_3d.py

# auditoria da prancha: vista sem tinta, tinta fora da moldura, texto sobreposto
python3 scripts/auditar_prancha.py --relatorio \
  designs/partition-120/cad/saida/passo2_relatorio.json
```

O passo 1 leva ~15 s, o 1b ~30 s (inclui a varredura de recuo), o 2 ~10 s e o render ~5 s.
Escrevem em `saida/`.

## Arquivos

| Arquivo | O que é |
|---|---|
| `biombo_passo1.py` | Passo 1: só a estrutura de metal. Aprovado; **não editar** |
| `biombo_passo1b.py` | Passo 1b: base decidida (4 rodízios + chapas soldadas). Reaproveita a construção do passo 1 |
| `saida/passo1_*` | Prancha A3 (PDF), lista de corte (CSV) e relatório do passo 1. O DXF e o STEP são gerados mas **não versionados** |
| `saida/passo1b_prancha.pdf` | **Prancha A3 do passo 1b** — 3 colunas × 2 linhas: planta, frente, lateral, isométrica 1:25 e detalhe da base 1:2 |
| `saida/passo1b_prancha.dxf` | Mesma folha em mm para CAD — **não versionado**: regenere com o script |
| `saida/passo1b_biombo.step` | Sólido do passo 1b — **não versionado**: regenere com o script |
| `saida/passo1b_lista_corte.csv` | Perfil, comprimento, quantidade (tubo + chapas + rodízios) |
| `saida/passo1b_relatorio.json` | Números medidos, varredura de recuo e resultado das verificações |
| `saida/passo1b_render_iso.png` | Render 3D isométrico (1920×1200) |
| `saida/passo1b_render_persp.png` | Render 3D em perspectiva (1920×1200) |
| `saida/passo1b_render_close.png` | Render 3D do close na base (1600×1200) |
| `saida/passo1b_render.txt` | Log do render (o `print` do script não sai no stdout nesse modo) |
| `saida/passo1b_biombo.FCStd` | Modelo FreeCAD (regenerável; não versionado) |
| `saida/passo2_prancha.pdf` | **Prancha A3 do passo 2** — duas faixas: as 4 vistas em cima; embaixo a placa decorada 1:20, a lista de material e as notas de fixação e montagem |
| `saida/passo2_prancha.dxf` | Mesma folha em mm para CAD — **não versionado** |
| `saida/passo2_biombo.step` | Sólido do passo 2 (67 peças) — **não versionado** |
| `saida/passo2_lista_corte.csv` | Tubo, chapa do rodízio, cantoneiras e placa |
| `saida/passo2_lista_compras.csv` | Compensado, parafusos e o acabamento opcional |
| `saida/passo2_relatorio.json` | Números medidos, verificações e o resultado da auditoria da prancha |
| `saida/passo2_render_iso.png`, `passo2_render_persp.png` | Renders 3D do conjunto montado (1920×1200) |
| `saida/passo2_render_close.png` | Render 3D do close em uma fixação (1600×1200) |
| `saida/passo2_biombo.FCStd` | Modelo FreeCAD do passo 2 (regenerável; não versionado) |

## Parâmetros do passo 1 (estrutura) — aprovado

Origem de cada número: `[B]` = veio do brief, `[P]` = proposta do agente.

| Parâmetro | Valor | Origem |
|---|---|---|
| Folha (largura × altura) | 900 × 1600 mm | [B] faixa 80–100 cm / total 150–180 cm |
| Perfil | metalon quadrado 30×30×1,5 mm | [B] "sweet spot" |
| Giro por junta | 60° → 120° internos | [B] núcleo do projeto |
| Travessa | 840 mm entre as faces internas dos montantes | [P] |

## Parâmetros do passo 1b (base decidida)

| Parâmetro | Valor | Origem |
|---|---|---|
| Rodízio | moveleiro Ø75 (3") com freio de ação total, roda de borracha, **altura total 102 mm**, placa 91,5 × 60 mm, carga 70 kg/un | [comercial] Leroy Merlin 1567099890 / IPC Comercial |
| Quantidade | **4 rodízios**: 2 na folha 1 e 2 na folha 3. A folha central fica pendurada nas juntas | [P] decisão do usuário |
| Cadeia de alturas | 102 (rodízio) + 4 (chapa) = **106 mm** até a base do quadro; topo em **1706 mm** | [P] medido do produto |
| Recuo do rodízio | 100 mm da ponta da folha, **dentro do plano da folha** | [P] ver varredura abaixo |
| Chapa soldada | 100 × 70 × 4 mm sob o pé do montante (na prática solda sob a travessa inferior), 4 rasgos oblongos 25 × 9 mm, passo 70 × 40 mm | [P] **passo dos furos a conferir** |

O pé em L de 150 mm chegou a ser projetado e foi **descartado**: perna no chão é risco de
tropeço no laboratório.

## Varredura do recuo (medida, não calculada)

Cada linha foi obtida construindo os sólidos dos rodízios e os montantes vizinhos e medindo
com `distToShape`. "Folga ao montante" é a menor distância entre qualquer peça do rodízio
(chapa, garfo, placa, roda) e o montante da folha vizinha, que é o que limita a aproximação.

| Recuo | Folga ao montante vizinho | Margem de tombamento | Tomba a |
|---|---|---|---|
| 80 mm | 0,0 mm (colide) | 197,2 mm | 12,70° |
| 90 mm | 4,5 mm | 188,6 mm | 12,16° |
| **100 mm** | **14,5 mm** | **179,9 mm** | **11,62°** |
| 110 mm | 24,5 mm | 171,3 mm | 11,07° |
| 120 mm | 34,5 mm | 162,6 mm | 10,53° |

Ficou em 100 mm: é o primeiro recuo com folga confortável ao montante vizinho. Aproximar mais
ganha pouca margem de tombamento (12,70° no limite, e colidindo) e encolher a folha de corte.

## Medições do passo 1b (saída do relatório JSON)

| Grandeza | Valor |
|---|---|
| Envoltória do conjunto | x 0,0…1357,5 · y −35,0…1560,9 · z 0…1706 mm |
| Tubo total | 14,64 m (igual ao passo 1) |
| Massa do tubo (seção vazada × comprimento) | 19,65 kg |
| Chapas soldadas | 4 × 100×70×4 → 0,88 kg |
| Massa fabricada (tubo + chapas) | 19,89 kg |
| Rodízios | 4 × Ø75, todos com Zmin = 0,000 mm (tocando o chão) |
| Folga mínima entre peças da base | 600,0 mm (`folha1_a_chapa` × `folha1_b_chapa`) |
| Interferência máxima entre peças de folhas diferentes | 0,000 mm³ |
| Folga mínima entre rodas | 625,0 mm |
| CG das peças fabricadas | (889,7 · 515,3 · 875,1) mm |
| CG dentro do polígono de apoio | sim |
| Margem de tombamento | 179,9 mm → tomba a **11,62°** |

Comparação de estabilidade medida no mesmo modelo: 6 rodízios recuados 100 mm → 16,7°;
4 rodízios (atual) → 11,62°; com o pé em L (descartado) → 24,24°.

A chapa soldada encosta na travessa inferior em todas as quatro posições (distância 0,000 mm),
e a 20 mm do montante — é sob a travessa que ela solda, não sob o montante.

## Parâmetros do passo 2 (placa de compensado decorado) — aprovado

Origem: `[U]` = decisão do usuário em 2026-09-18, `[P]` = proposta do agente derivada da
geometria e medida no sólido.

| Parâmetro | Valor | Origem |
|---|---|---|
| Painel | compensado decorado 15 mm, **834 × 1534 mm** | [U] placa de 15 mm; o recorte vem do vão de 840 × 1540 |
| Folga ao tubo | 3,0 mm em todo o contorno | [P] é o vão ocupado pela perna A da cantoneira |
| Posição | centrado na profundidade do tubo: −7,5 a +7,5 mm do plano médio da folha | [P] |
| Altura do painel | 139 a 1673 mm (Z0+33 até Z1−33) | [P] medido no modelo |
| Cantoneira | chapa dobrada em L, 25 × 25 × 3 mm, altura 25 mm | [U] |
| Cantoneira — perna A | 22,5 × 25 mm, soldada **de face** na face interna do montante | [U] |
| Cantoneira — perna B | 25 × 25 mm, deitada **sobre** a face do compensado | [U] |
| Cantoneira — quantidade | 4 por folha, 12 no total, em Z0+200 (306 mm) e Z0+1340 (1446 mm) | [P] |
| Furo da aba | Ø4,2 mm, a 15 mm da face interna do montante | [P] |
| Parafuso | madeira Ø4 × 16 mm, cabeça panela Ø8 mm, furo piloto Ø2,5 mm, 12 unidades | [P] |
| Acabamento (espuma + tecido) | **em aberto, e não modelado** | [U] em 2026-09-18: a prancha mostra só a placa decorada |
| Acabamento, se houver | espuma 3 mm + tecido <1 mm por face | [U] desloca a cantoneira 4 mm e pede parafuso Ø4 × 20 |

### Fixação: cantoneira em L, e por que assim

O parafuso de madeira só é acionável na direção da normal do painel — é a única em que a chave
chega ao vão entre o tubo e a placa. Logo a peça soldada tem de apresentar uma face
perpendicular a essa normal sobre a placa, e é isso que a perna B faz.

- soldar **de face** (perna A encostada na face interna do montante) dá 22,5 × 25 mm de contato
  na parede do tubo, e o gabarito de solda vira só encostar a perna A na face interna;
- a perna A tem 3 mm de espessura e é ela que define a folga de 3 mm entre a placa e o tubo: a
  placa apoia na perna A e o parafuso aperta contra ela. Não mude uma coisa sem mudar a outra;
- a cabeça Ø8 fica entre 10,5 e 12,1 mm do plano médio — abaixo da face do tubo (15 mm) e fora
  da pegada do estofamento, que começa a 30 mm da borda: não briga com o acabamento;
- o parafuso de 16 mm são 3 mm na perna B + 13 mm na placa, com 2 mm de fundo. Não atravessa.

### Ordem de fabricação (está na prancha)

1. Soldar as 4 cantoneiras de cada folha no gabarito, nas alturas Z0+200 e Z0+1340, centradas na
   profundidade do tubo.
2. Parafusar a placa **nua** nas cantoneiras: 4 parafusos Ø4 × 16 por folha, furo piloto Ø2,5
   feito pelo furo da aba.
3. Se houver acabamento: colar a espuma nas duas faces e grampear o tecido na borda de 20 mm da placa.
4. Com acabamento, a cantoneira solda com o painel já estofado e o parafuso passa a Ø4 × 20.

Depois do passo 2 não há mais acesso aos parafusos: é a ordem acima ou nada.

## Medições do passo 2 (saída do relatório JSON)

| Grandeza | Valor |
|---|---|
| Peças do conjunto | 67 (28 do quadro e da base + 3 placas + 12 cantoneiras + 24 parafuso e cabeça) |
| Massa fabricada | **55,32 kg** = tubo 19,652 + placa 34,543 + chapas 0,766 + cantoneiras 0,332 + parafusos 0,026 |
| Massa do painel por folha | 11,51 kg |
| Carga por rodízio | 13,8 kg (limite 70 kg/un) |
| CG do conjunto | (898,4 · 520,5 · 894,7) mm |
| Margem de tombamento | **175,0 mm → tomba a 11,07°** (passo 1b: 179,9 mm / 11,62°) |
| Sensibilidade do compensado | 550 kg/m³ → 52,44 kg / 11,08°; 600 → 55,32 kg / 11,07°; 650 → 58,20 kg / 11,06° |
| Espessura do painel | 15,0 mm (só a placa: o acabamento não entra no modelo) |
| Folga da placa aos tubos | 3,0 mm, a mínima, nos 4 tubos de cada folha |
| Contato das cantoneiras | 0,000 mm nas 12, nas duas pernas (perna A no montante, perna B na placa) |
| Volume da cantoneira | 3.520,9 mm³ por peça, medido; o nominal 3.337,5 do primeiro rascunho estava errado (descontava o canto do L duas vezes) |
| Parafuso dentro da placa | 163,363 mm³ por par — 13 mm de rosca, por projeto |
| Interferência entre montantes vizinhos | 207.846,097 mm³ em cada uma das duas juntas — **herdada do passo 1b**: é o canto do encontro a 120°. O detalhe da junta é o passo 3 |
| Altura total | 1706 mm; o painel para em 1673 mm, dentro do quadro |
| Área útil da prancha ocupada | 17,9 % |
| Auditoria da prancha | 47 textos, nenhum sobreposto, nenhum fora da moldura; nenhuma vista sem tinta |

## Vistas da prancha

`Frente` é a vista perpendicular à **folha central** (a placa do meio), do lado côncavo — a
vista simétrica do biombo. `Lateral` é a paralela às **folhas das pontas**. Isso está invertido
em relação ao passo 1, onde a "frente" era a vista paralela às folhas das pontas.

| Vista | Direction | XDirection | Extensão medida |
|---|---|---|---|
| Frente (folha central de frente) | (−0,866 · 0,500 · 0) | (−0,500 · −0,866 · 0) | 1826 × 1706 mm |
| Lateral (paralela às folhas das pontas) | (0 · −1 · 0) | (1 · 0 · 0) | 1357,5 × 1706 mm |
| Planta (de cima, mesma direita da frente) | (0 · 0 · −1) | (−0,500 · −0,866 · 0) | 1826 × 807,4 mm |
| Isométrica 1:25 | (1 · −1 · 1) | (1 · 1 · 0) | 1770 × 2001 mm |
| Detalhe da base 1:2 | (0 · 0 · −1) | (1 · 0 · 0) | 150 × 70 mm |

A vista oblíqua é o caso que exige `centrar_no_conteudo=True` no `Projetor.vista` — sem isso
as cotas ancoradas em ponto do modelo caem fora da caixa da vista. Ver
[docs/cad-workflow.md](../../../docs/cad-workflow.md).

Folha A3 em grade de 3 colunas (`x` = 38 / 165 / 292 mm) por 2 linhas (`y` = 172 / 48 mm), com
o carimbo no canto inferior direito. Área útil ocupada pelas vistas: 23,5 % (a folga entre
colunas é o que as cotas verticais usam).

### Folha do passo 2

Duas faixas, separadas por uma linha horizontal imaginária no meio da folha. Em cima, as quatro
vistas na escala do 1b: `Iso` (1:25), `Frente` (1:25, perpendicular à folha central), `Lateral`
(1:25) e `Topo` (1:25, a que mostra o ângulo de 120°). Embaixo, três blocos: `Compensado`
(1:20 — a placa de 834 × 1534 cotada, com a posição dos 4 furos de parafuso), a lista de
material e as notas de fixação e montagem. Carimbo no canto inferior direito:
`BIOMBO 120 - PASSO 2: PLACA DE COMPENSADO DECORADO`.

## Correção de um número errado do passo 1

A primeira versão deste arquivo dizia que, nas pontas, "os rodízios de folhas vizinhas caem a
26 mm um do outro e a roda tem 75 mm — colidem". Medido nos sólidos do passo 1:

| Par | Distância |
|---|---|
| centros das rodas | 173,2 mm |
| roda × roda | 92,3 mm |
| garfo × garfo | 115,4 mm |
| placa × placa | 60,3 mm |
| **placa × montante da folha vizinha** | **19,5 mm** ← é este que limita |

Nada colide: o que limita a aproximação é a chapa do rodízio contra o montante da folha
vizinha.

## Decisões fechadas no passo 1b

- **Rodízio comercial.** Linha moveleira Ø75 com freio, altura 102 mm, carga 70 kg/un. A linha
  industrial (Schioppa 3", 200 kg, R$ 149,95) foi descartada: altura de 154 mm e roda de ferro
  fundido, que o anúncio diz não servir para piso sensível nem para baixo ruído.
- **Quantidade e posição.** 4 rodízios, 2 por folha, só nas folhas das pontas, recuados
  100 mm dentro do plano da folha. Sem pé em L.
- **Chapa de base.** 100 × 70 × 4 mm soldada sob a travessa inferior, com 4 rasgos oblongos.

## Pendências

- **Furação da chapa.** Nenhuma fonte consultada publica o passo entre os 4 furos da placa do
  rodízio (a Leroy dá altura 102, banda 32, cubo 40, raio de giro 65, carga 70; a IPC dá a
  placa 60 × 91,5 "4 furos oblongos"). O desenho usa rasgo oblongo 25 × 9 com passo 70 × 40,
  que tolera variação entre modelos, e a prancha diz **CONFERIR com o rodízio comprado**.
- **Folha central sem apoio.** Com 4 rodízios, a folha 2 fica pendurada nas duas juntas e o pé
  dela permanece 106 mm acima do chão. Ao mover ou dobrar o biombo, o peso dela (≈6,5 kg de
  estrutura, mais o painel) passa pelas dobradiças — o passo 3 precisa confirmar que a
  dobradiça aguenta e que não há folga que deixe a folha central raspar o piso.
- **Peso do painel.** Resolvido no passo 2: 11,51 kg por folha, medidos, derrubaram a margem de
  179,9 mm (11,62°) para 175,0 mm (11,07°). O acabamento (espuma + tecido) não está modelado:
  se existir, o CG sobe um pouco mais.
- **Acabamento do painel em aberto.** Qual espuma, qual tecido, e se existem. O modelo trata
  como opcional (3 + 1 mm por face) e não desenha. A decisão muda a cantoneira (4 mm de
  deslocamento para fora) e o parafuso (passa a Ø4 × 20).
- **Interferência na junta.** Os montantes vizinhos se sobrepõem 207.846 mm³ (207,8 cm³) no
  encontro a 120°, nas duas juntas — geometria herdada do passo 1b. O corte das pontas e a
  dobradiça são o passo 3.

## Próximos passos

1. Acabamento do painel: decidir espuma e tecido, ou decidir não fazer. Se fizer, a cantoneira
   desloca 4 mm para fora e o parafuso vira Ø4 × 20 — só essa parte do passo 2 precisa ser
   refeita.
2. Passo 3: dobradiça no encontro a 120°, onde os montantes vizinhos hoje se sobrepõem
   207,8 cm³, e detalhe ampliado da chapa com a furação confirmada contra o rodízio comprado.
3. Conferir o que acontece com o biombo dobrado: a folha central pendurada (o painel dela, de
   11,51 kg, pende só das juntas), o empilhamento contra a parede.

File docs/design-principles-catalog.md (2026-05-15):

# Design Principles Catalog

A collection of design principles extracted from multiple philosophies and sources. Presented as a **reference catalog** for evaluation — no principles are adopted as requirements yet.

---

## Spatial Geometry

### 120° Instead of 90°

**Source:** Robert Propst, *The Office: A Facility Based on Change* (1968)

Right angles are building geometry, not human geometry. Three panels at 120° form a partial enclosure ("amphitheater") that:
- Provides partial enclosure without cell-like feeling
- Preserves peripheral vision
- Creates natural entry/exit flow
- Eliminates the dead corner of cubicles
- Is better for collaborative pair work

**Applied to benches:** A 120° angle between work surface and whiteboard/pegboard panel creates a natural "bay" that encloses without confining. Two students can work side by side without invading each other's space.

**Counterargument:** 120° layouts use more floor area per station than 90° grids. In a 49m² lab, every square meter matters.

---

### Organic Layout (No Grid)

**Source:** Bürolandschaft, Quickborner Team (1960s)

Arrange furniture based on actual communication and workflow patterns, not on a rectangular grid. Result is typically asymmetrical and plant-integrated.

**Counterargument:** Difficult to implement in small spaces. Requires prior study of workflows. Can look disorganized.

---

### Universal Grid

**Source:** OpenStructures, Thomas Lommée

Define a standard grid (e.g., 40×40 mm hole pattern) that all components share. Everything is interoperable by default.

**Applied to benches:** A lab-wide grid standard means a pegboard from one bench clips onto the frame of another. Tool holders, shelves, and panels are interchangeable across all workstations.

**Counterargument:** Constrains design freedom. Requires discipline and documentation to maintain.

---

## Ergonomics and Posture

### Postural Variation

**Source:** Propst (1968); modern ergonomic research

A worker should not maintain the same posture for 8 hours. Each station should offer multiple surface heights:
- Low surface for seated concentration
- High surface for standing work or brief meetings
- Intermediate surfaces for leaning/perching

**Applied to benches:** The soldering bench is standing-height by design. Could a secondary lower shelf provide a seated option? The workstation 120° could have an adjustable monitor arm + keyboard tray for sit/stand.

---

### Task-Appropriate Height

**Source:** Propst; kitchen station design; industrial ergonomics

Different tasks have different optimal heights:
- Precision soldering: elbow height or slightly above (standing)
- CAD work: standard desk height (seated) or adjustable
- Assembly/mechanical: slightly below elbow height for leverage
- Reading/discussion: counter height for standing meetings

**Counterargument:** Adjustable-height mechanisms (linear actuators) add cost and complexity.

**Practical data:** See [ergonomics.md](ergonomics.md) for anthropometric data (Brazilian population), ideal desk heights, and elbow angle tolerances. See [adjustable-height-mechanisms.md](adjustable-height-mechanisms.md) for telescoping tube combinations and DIY locking mechanisms.

---

## Vertical Surfaces

### Walls as Mental Extension

**Source:** Propst (1968)

Vertical surfaces around the workstation are for pinning, displaying, organizing — not decoration. Information is externalized into the visual field. The modern equivalent: whiteboard + Kanban board + pegboard.

**Applied to benches:**
- Soldering bench: pegboard for tools (soldering iron, hot air, probes, tweezers)
- Workstation 120°: pegboard for monitor mount + small shelf for components + whiteboard for schematics

---

### Shadow Boards

**Source:** 5S methodology (Japanese manufacturing)

Every tool has a painted/engraved outline showing where it belongs. Missing tools are instantly visible.

**Applied to benches:** Pegboard with laser-cut outlines or printed backgrounds showing where each tool lives.

---

## Privacy and Acoustics

### Gradual Privacy (Not Binary)

**Source:** Propst (1968); Activity-Based Working

Privacy is a spectrum, not a toggle. Design for:
- **High privacy** — Focus pods, enclosed booths (for deep coding/debugging)
- **Medium privacy** — Semi-enclosed bays, 120° panels (for concentrated electronics work)
- **Low privacy** — Open tables, standing benches (for collaboration, assembly)

**Applied to lab:** The 7×7m space could have a noise/focus gradient — quiet zone (CAD) on one end, noisy zone (mechanical/CNC) on the other, medium (electronics) in between.

---

### Noise Gradient

**Source:** Activity-Based Working; Propst

Organize space so incompatible noise levels don't overlap. Quiet tasks (coding, reading datasheets) should be far from noisy tasks (drilling, CNC, grinding).

**Applied to LaRA 7×7m:** CAD zone distant from CNC/mechanical zone. Electronics in the middle.

---

## Adaptability

### Everything on Casters

**Source:** Fun Palace (Cedric Price); Propst; Activity-Based Working

If it doesn't absolutely need to be fixed to the wall or floor, it should have casters with brakes. Layout changes in minutes, not days.

**Applied to benches:** Both the soldering bench and workstation 120° are designed to be mobile. Heavy equipment (CNC, 3D printers) stays fixed; workstations move.

**Counterargument:** Mobile benches need cable management solutions (retractable reels, overhead drops). Caster quality matters — cheap casters on a loaded bench are worse than fixed legs.

---

### Modular Frames (Profile Systems)

**Source:** Open Source Ecology; OpenStructures; industrial workstations

Use aluminum extrusion (V-slot, Bosch, 80/20) instead of welded steel or glued wood. Everything is bolted, nothing is permanent. A bench can grow, shrink, or reconfigure by moving a few brackets.

**Applied to benches:** Both active designs could use 4040 or 2040 profile as the structural frame. Pegboard panels, shelves, and accessories mount with standard T-slot brackets.

---

## Organization and Maintenance

### 5S for Academic Labs

**Source:** Japanese manufacturing methodology; adapted for university labs

The five pillars, adapted for a lab with 30+ rotating students:
1. **Seiri (Sort)** — Remove everything not needed for current projects. Expired components, broken tools, abandoned prototypes.
2. **Seiton (Set in order)** — Shadow boards, labeled drawers, Kanban for consumables. New student finds any tool in 30 seconds.
3. **Seiso (Shine)** — Clean bench after every session. Soldering station cleaned, tools returned, waste disposed.
4. **Seiketsu (Standardize)** — Same bench layout, same tool location, same process across all stations.
5. **Shitsuke (Sustain)** — Formal end-of-session checklist. Weekly audit by infra student. Without this, degrades in 6 months.

**The 30-second rule:** If a new student cannot find a tool in 30 seconds, the organization has failed.

---

### Project-in-Progress (PIP) Policy

**Source:** Lab management practice

The "trash" in academic labs is mostly abandoned projects from graduated students. Policy:
- Shelves numbered with labels: owner / project / date
- No update for N months → return to stock or recycle
- Formal handoff before student leaves (disassemble, document, or donate)

---

## Material and Aesthetic Choices

### Typical Palette for This Philosophy

Common across Propst-inspired, activity-based, and maker environments:
- Light wood (birch plywood, maple)
- Thin black steel/metal frame
- Glass or acrylic panels
- Diffused lighting (task + ambient)
- Plants (biophilic design)
- Perforated metal / pegboard
- Wheels and casters
- Open shelving (not closed cabinets)

### Industrial Examples

- Steelcase workstations
- Vitra office systems
- Premium coworking spaces
- Post-pandemic hybrid offices
- Adam Savage's Tested workshop
- MIT Media Lab spaces
- Stanford Product Realization Lab

---

*This is a catalog of options. Individual project briefs will reference specific principles as needed.*

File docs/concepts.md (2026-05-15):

# Concepts

Catalog of workspace design philosophies, presented as **options** for evaluation. No decisions made yet.

---

## 1. Robert Propst — *The Office: A Facility Based on Change* (1968)

**Origin:** Research at Herman Miller with environmental psychologists and behavioral scientists. The book that inspired the Action Office system — and was later distorted into the cubicle.

**Core idea:** Workspaces must change as work changes. The facility is a living system, not a fixed floor plan.

**Key principles:**
- **120° angles, never 90°** — Right angles are building geometry, not human geometry. Three panels at 120° create a partial enclosure that preserves peripheral vision, creates natural entry/exit flow, and eliminates dead corners.
- **Postural variation** — 8 hours in a chair degrades body and cognition. Each station should offer multiple surface heights: low table for seated focus, high bench for brief standing meetings, shelves for leaning/moving.
- **Vertical surfaces as mental extension** — Walls and panels around the station are for pinning, displaying, organizing — not decoration. Information externalization through the visual field.
- **Gradual privacy** — Not binary (closed room vs. open plan). A gradient: high privacy for deep focus, medium for connected concentration, low for collaboration.
- **Radical adaptability** — "Facility based on change" is the principle AND the title. Work changes, teams change, projects change; space reconfigures in hours, not construction.
- **Task differentiation** — Uniform benches are a mistake. Different tasks need different ergonomics, lighting, tools, and privacy levels. The office should look more like a professional kitchen (specialized stations) than a classroom (identical rows).
- **Functional egalitarianism** — Against the "corner office = power" model. Everyone deserves functional space for their actual task; nobody deserves trophy-space for status.

**What went wrong:** Companies froze the layouts to save money. The modular system became static cubicles — exactly the opposite of what Propst intended.

**Pros for LaRA:**
- Strong theoretical foundation with behavioral research
- Directly applicable to bench and lab design
- The 120° principle creates natural collaboration bays

**Cons / Critiques:**
- Designed for office knowledge work, not physical making
- Doesn't address dust, fumes, ESD, heavy equipment
- The cubicle failure shows good principles can be corrupted by cost-cutting

**Further reading:** Herman Miller official page on the work: https://www.hermanmiller.com/stories/why-magazine/the-office-documented/

---

## 2. Bürolandschaft (Quickborner Team, Hamburg, 1960s)

**Origin:** Eberhard and Wolfgang Schnelle developed this in Germany as a response to rigid corporate layouts. Inspired by landscape design — organic, flowing, non-grid.

**Core idea:** Layout follows the actual flow of information and communication between people, not architectural symmetry. Map who talks to whom, then arrange desks accordingly.

**Key principles:**
- **Organic layout** — No grid. No straight rows. Desks placed according to real communication patterns.
- **Flow-based arrangement** — Map paper/information flow before designing space. Result is almost never symmetrical.
- **Plants and curved dividers** — Break straight lines with biophilic elements and curved screens.
- **Landscape metaphor** — Office as a landscape with hills (partial screens), paths (circulation), clearings (meeting areas).

**Pros for LaRA:**
- Relevant for a lab with 30+ students where collaboration patterns matter
- Encourages mapping actual workflows before committing to layout
- Anti-grid philosophy pairs well with Propst's 120° principle

**Cons / Critiques:**
- Requires detailed study of communication patterns first
- Can look messy/unstructured to traditional eyes
- Harder to implement in a small 7×7m space — needs room for organic flow

**Reference:** Look for photos of the Buch und Ton office (1961) and Bertelsmann headquarters.

---

## 3. OpenStructures (Thomas Lommée, 2009–present)

**Origin:** Belgian designer Thomas Lommée created an open modular building system based on a universal 4×4 cm grid.

**Core idea:** Define a universal grid standard. Anyone can design components that connect to anyone else's components. Interoperability by design.

**Key principles:**
- **Universal grid (4×4 cm)** — All components share the same mounting pattern
- **Interoperability** — Any bench connects to any shelf connects to any panel
- **Open standard** — Anyone can design new parts that fit the system
- **Cumulative design** — The system grows as more people contribute

**Pros for LaRA:**
- Could define a grid standard for the lab (e.g., 40×40 cm, or multiples of V-slot profile)
- Student-designed benches would automatically be compatible
- Aligns with open hardware philosophy

**Cons / Critiques:**
- The 4×4 cm grid may be too small for furniture-scale work
- Requires discipline to maintain standard compliance
- Less documentation/examples than traditional approaches

**Website:** https://openstructures.net

---

## 4. Open Source Ecology — Global Village Construction Set (Marcin Jakubowski)

**Origin:** Marcin Jakubowski's project to create 50 open-source industrial machines for building civilization from scratch.

**Core idea:** The lab builds its own lab. Infrastructure is self-replicating and open.

**Key principles:**
- **Self-replication** — Machines that can make other machines
- **Open documentation** — Complete build instructions, BOM, CAD files
- **Modular** — Components shared across machines
- **Distributed production** — Anyone can build anywhere

**Pros for LaRA:**
- First student cohort could build the lab furniture as their initiation project
- CNC can cut bench parts — the lab literally makes itself
- Strong documentation culture from the start

**Cons / Critiques:**
- More focused on heavy industrial equipment than precision lab work
- Aesthetic is utilitarian, not refined
- Time investment before having usable infrastructure

**Website:** https://opensourceecology.org

---

## 5. Cedric Price — Fun Palace (1961, unbuilt)

**Origin:** Architect Cedric Price designed a building where walls, floors, and stairs would be reconfigured daily by cranes based on the activity. Never built, but hugely influential.

**Core idea:** Architecture as infrastructure, not form. The building is a kit of parts; the users decide the configuration.

**Key principles:**
- **Everything reconfigurable** — Nothing fixed. Walls, floors, stairs change daily.
- **Infrastructure as service** — Building provides power, water, structure. Users provide the layout.
- **Time-based design** — Space changes over time by design, not despite design.
- **Anti-monument** — The building should be unremarkable; the activity is what matters.

**Pros for LaRA:**
- Radical version of "everything on casters" philosophy
- Validates the idea that lab layout should change with each project/semester
- The "infrastructure as service" model fits well with overhead power/air drops

**Cons / Critiques:**
- Extreme — never actually built even by its designer
- Requires significant overhead infrastructure (power rails, cable management)
- Not practical for heavy equipment (CNC, 3D printers)

**Influence:** Centre Pompidou, MIT Media Lab.

---

## 6. Lina Bo Bardi — SESC Pompéia (São Paulo, 1977–86)

**Origin:** Brazilian architect transformed a drum factory into a community center with workshops, library, sports, theater. All furniture designed to be reconfigured by users.

**Core idea:** Workspace as public, living space. No hierarchy between activities. Users reshape the environment.

**Key principles:**
- **User reconfiguration** — Furniture designed to be moved, stacked, rearranged by non-experts
- **No hierarchy** — Woodworking, ceramics, printing all share equal space and dignity
- **Industrial heritage** — Embrace the raw character of industrial spaces
- **Social space** — Work is public and communal, not hidden in back rooms

**Pros for LaRA:**
- Brazilian reference with rich documentation (Instituto Lina Bo e P.M. Bardi)
- Anti-cubicle philosophy with warmth and humanity
- Shows that lab can be visible/performative (glass walls, open to corridor)

**Cons / Critiques:**
- Community center context is different from university research lab
- Aesthetic may be too rustic for precision electronics work
- Less focused on individual workstation ergonomics

---

## 7. Salk Institute — Louis Kahn (1965)

**Origin:** Jonas Salk (polio vaccine) commissioned Louis Kahn to design a biological research institute. The result is almost monastic — labs as contemplative space.

**Core idea:** "Served vs. servant spaces." Research spaces (served) are clean, open, flexible. Infrastructure spaces (servant — ducts, pipes, power) are separated into interstitial floors.

**Key principles:**
- **Served vs. servant** — Separate where you work from where the infrastructure lives
- **Contemplative quality** — Research benefits from architectural quality and beauty
- **Flexible open labs** — Large open spaces that can be subdivided as needed
- **Infrastructure in interstitial floors** — Power, air, data accessible without entering the lab

**Pros for LaRA:**
- The "served vs. servant" idea applies even at bench scale (cable management trays, overhead rails)
- Validates investing in architectural quality for a research space
- Open lab concept with subdivision potential

**Cons / Critiques:**
- Monumental scale doesn't translate directly to a 7×7m room
- Budget reality of a university lab vs. a Salk-commissioned building
- Interstitial floors are not feasible in most existing buildings

---

## 8. Activity-Based Working (ABW)

**Origin:** Modern workplace strategy (Veldhoen + Company, 1990s) where employees choose from a variety of settings based on the task at hand.

**Core idea:** No assigned desks. Instead, a menu of activity settings — each optimized for a specific type of work.

**Key principles:**
- **Task-based settings** — Library zone, collaboration zone, focus booth, standing bench, lounge
- **Choice** — Workers select the environment that matches their current activity
- **Shared resources** — Everyone has access to everything; nothing is "owned"
- **Density optimization** — Because not everyone uses every space simultaneously, total footprint is efficient

**Pros for LaRA:**
- Maps well to a lab with diverse activities (soldering, coding, assembly, testing)
- Could define distinct zones in the 7×7m space
- Reduces the "my desk" territoriality problem in shared labs

**Cons / Critiques:**
- Requires enough variety of settings to actually offer choice
- Storage/personal items need separate solution when there are no assigned desks
- Can feel impersonal without personal territory

---

## Summary Table

| Philosophy | Origin | One-line takeaway | Scale fit for LaRA |
|---|---|---|---|
| Propst / Action Office | 1968, USA | Space must change as work changes | Direct — bench and room scale |
| Bürolandschaft | 1960s, Germany | Layout follows communication flow | Room scale (with study) |
| OpenStructures | 2009, Belgium | Universal grid = universal interoperability | Component scale |
| Open Source Ecology | 2000s, USA | The lab builds itself | Project-scale philosophy |
| Fun Palace | 1961, UK | Everything reconfigurable, nothing fixed | Aspirational |
| SESC Pompéia | 1977, Brazil | Workspace as living public space | Vibe/aesthetic reference |
| Salk Institute | 1965, USA | Served vs. servant spaces | Conceptual (interstitial trays) |
| Activity-Based Working | 1990s, Netherlands | Choose your setting based on your task | Zone organization |

---

*No philosophy has been chosen. These are options for evaluation as the project develops.*

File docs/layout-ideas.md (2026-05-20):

# Layout Ideas

Spatial organization concepts for the LaRA lab. All options — no decisions made.

---

## LaRA Lab — 7×7m Layout Option

### Constraints

- **Room:** 7m × 7m (49m²)
- **North wall:** Full window (entire wall)
- **South wall:** 2 doors — one at far left (southwest), one at far right (southeast)
- **East and west walls:** Solid, full-height
- **Equipment:** CNC machine + heavy bench (stays fixed), 2×2m robot test table (center)
- **3D printers:** Located in another room (fumes/odor)

### Layout Proposal

**Zoning logic:**
- Perimeter = productive zones (benches against walls)
- Center = robot test table (2×2m) with ~1m circulation on each side
- Noise gradient: quiet (north, window) → medium (east) → loud (southwest, CNC)

**Zones:**

| Zone | Location | Activity | Noise |
|---|---|---|---|
| Electronics bay (V, 120°) | North (window) | Soldering, debug, prototyping | Low–Medium |
| CAD stations (×4) | East wall | Programming, CAD, documentation | Low |
| CNC + heavy bench | Southwest corner | Machining, drilling, assembly | High |
| Whiteboard + Kanban | South wall (between doors) | Planning, project status | — |
| Robot test table (2×2m) | Center | Robot testing, demos, assembly | Variable |

**Circulation:**
- Right door (southeast) = clean entry → CAD, electronics
- Left door (southwest) = service entry → CNC, material in/out
- U-shaped flow around the central table

### Floor Plan (SVG)

LaRA 7×7m Floor Plan

---

## Layout Variations to Explore

### Option A: Propst-Style 120° Clusters

Three electronics benches in a 120° V-formation near the window, forming a collaborative bay. CAD stations along the east wall with whiteboard panels between them. CNC isolated in the southwest corner.

**Pros:** Applies 120° principle directly. Natural collaboration bays.
**Cons:** 120° uses more floor area per station. Tight fit in 49m².

### Option B: Bürolandschaft Organic

No straight lines. Benches arranged organically based on communication flow between research groups. Plants as dividers. Curved circulation paths.

**Pros:** More human, more interesting visually.
**Cons:** Harder to plan. Needs workflow study first. Less predictable density.

### Option C: Grid + Modular (OpenStructures)

Define a 40×40cm or 60×60cm grid for the entire lab. All benches, shelves, and panels align to the grid. Easy to reconfigure. Everything interoperable.

**Pros:** Maximum flexibility and interoperability.
**Cons:** Constrains design. Can feel rigid despite being modular.

### Option D: Activity-Based Zones

Divide the lab into named zones by activity, not by equipment. Zones: "Focus" (CAD), "Precision" (electronics), "Fabrication" (CNC), "Test" (robot table), "Plan" (whiteboard). Each zone optimized for its activity.

**Pros:** Clear purpose for each area. Easy to explain to new students.
**Cons:** Zones may conflict when multiple activities need the same space.

### Option E: Hexagonal Focus Bay

Six Habitat modules arranged in a hexagon, forming a semi-enclosed collective focus environment. Each module's edges are cut at 60° so that adjacent modules meet at 120° — the project's core angle.

**Composition (hybrid):**

| Side | Module | Facing | Function |
|---|---|---|---|
| 1 | Workstation 120° | Inward | Individual CAD/programming station |
| 2 | Workstation 120° | Inward | Individual CAD/programming station |
| 3 | Workstation 120° (or Partition) | Inward / closure | Station or acoustic panel |
| 4 | Partition 120° | Inward | Acoustic + visual closure |
| 5 | Partition 120° | Inward | Acoustic + visual closure |
| 6 | Open (entrance) | — | No module, or low partition / Break Pod |

**Geometry:**
- Internal angle: 120° at each vertex
- Estimated internal diameter: ~2.5–3m (depends on module width)
- Module edge cut angle: 60° (half of 120° vertex)
- Footprint: ~7–9m² (fits within the 49m² lab)

**Properties:**
- Creates a shared focus zone without walls or construction
- Each person has their own station but shares the enclosed environment
- Fully reconfigurable — disassemble into individual modules and rearrange in minutes
- Complementary to the Focus Pod (individual) — this is the collective equivalent
- Naturally absorbs the 120° angle of each module — no custom joints or adapters

**Pros:** Applies 120° principle at room scale. Modular — assemble and disassemble as needed. Creates strong collective focus without construction.
**Cons:** Requires 6 modules minimum. Occupies significant floor area. Module edges need specific cut angles for clean joints. Cable management for workstations inside the bay needs a solution.

**Implications for module design:**
- Modules need clean edges at 60° cuts on the joining sides
- Consistent frame height at the joint line for alignment
- No protruding elements (handles, casters) at joint edges
- Optional mechanical connection (clips, magnets, brackets) between modules

**Pentagon alternative (5 modules, 108°):**
Fewer modules needed, but 108° doesn't align with the 120° principle. Would require module edges cut at 54° — a different geometry. Explored as a concept but hexagon is the primary direction. See reference images in the main README.

---

## Lessons from History

From the office design evolution video and Propst's work:

1. **Design for the task, not the ideology** — Don't build an "open lab" or a "modern lab." Build for what people actually do.
2. **Observe before designing** — Watch how the lab works now. Where do people gravitate? Where are the bottlenecks? Layout should follow behavior.
3. **The Propst trap** — Good modular design gets frozen into rigid layouts by cost/effort pressure. Build in explicit reconfiguration rituals (monthly layout review?).
4. **The Harvard study finding** — Open plans reduce face-to-face communication, not increase it. Partial enclosure (120° panels, semi-private bays) actually encourages collaboration more than full openness.

---

## Planning Resources

### Search Terms for Floor Plans
- `robotics lab floor plan`
- `university makerspace layout`
- `FabLab floor plan`
- `electronics lab workbench layout`
- `activity based working floor plan`

### Tools for Drawing
- **FreeCAD** — Arch workbench for 2D floor plans
- **Sweet Home 3D** — Quick residential-scale layout tool
- **LibreCAD** — 2D-only CAD, good for floor plans
- **Draw.io / diagrams.net** — Quick schematic layouts, not to scale
- **SVG** — Direct authoring (what we'll use for initial concepts)
- **Inkscape** — SVG editor for refining floor plans

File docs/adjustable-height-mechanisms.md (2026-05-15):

# Adjustable Height Mechanisms

Practical solutions for building height-adjustable desk/workstation legs without electric actuators. Focuses on materials and techniques accessible in Brazil.

---

## 1. Telescoping Square Steel Tubing (Metalon)

### Combinações que encaixam

Tubos quadrados de aço (metalon) com dimensões comerciais brasileiras (NBR 6591/8261, ASTM A500). A tabela abaixo mostra combinações onde o tubo interno desliza dentro do externo com folga mínima.

| Tubo externo | Parede ext. | Diâmetro interno | Tubo interno (ext.) | Folga por lado |
|---|---|---|---|---|
| **50x50** | 3,75 mm | ~42,5 mm | **40x40** | **~1,25 mm** |
| 50x50 | 3,00 mm | ~44,0 mm | 40x40 | ~2,0 mm |
| 40x40 | 2,65 mm | ~34,7 mm | 30x30 | ~2,35 mm |
| 30x30 | 2,25 mm | ~25,5 mm | 25x25 | ~0,25 mm (muito justo) |

### Par recomendado: 50x50 (esp 3,75mm) + 40x40

- ~1,25 mm de folga por lado — suficiente para deslizar sem travar
- Com bucha de nylon ou fita UHMW no interior, fica firme sem holgura
- 2 colunas telescópicas suportam uma mesa com folga
- Para maior rigidez: 3 ou 4 colunas

### Reduzindo vibração e folga

- **Bucha de nylon** usinada ou cortada e inserida nas extremidades do tubo externo
- **Fita UHMW** (Ultra High Molecular Weight polyethylene) aplicada nas faces internas de deslizamento
- **Parafuso prisioneiro** (set screw) no tubo externo para eliminar folga residual após travar
- **Graxa ou cera** nas superfícies de deslizamento para reduzir ruído e desgaste

### Fontes de tubo no Brasil

- Cia do Ferro — https://ciadoferro.com.br/tubo-quadrado/
- Grupo Aparecida Tubos — https://www.aparecidatubos.com.br/tubos-quadrado
- Century Tubos — https://materiais.centurytubos.com.br/catalogo
- K-Ferros — https://kferros.com.br/tubo-industrial-quadrado/1941
- Tabela completa de medidas: Fábrica do Projeto — https://www.fabricadoprojeto.com.br/tabelas-de-laminados-trefilados-e-itens-comerciais/tabelas-fapro-tubo-industrial-quadrado/

---

## 2. Locking Mechanisms

### 2.1 Pino + Furos (Pin Lock)

| Aspecto | Detalhe |
|---|---|
| **Complexidade** | Baixa |
| **Custo** | ~R$ 10 |
| **Ajuste** | Discreto (a cada ~25 mm) |
| **Pros** | Simples, robusto, sem vibração, fácil de fabricar |
| **Contras** | Ajuste não-contínuo; precisa furar ambos os tubos |

**Como fazer:**
1. Furar o tubo externo em múltiplas posições (ex: a cada 25 mm)
2. Furar o tubo interno nas alturas desejadas
3. Inserir pino (parafuso, pino quick-release, ou pino com mola/bola tipo bicicleta)

**Pino quick-release (pino com mola/bola):** encontrado em lojas de bicicleta ou camping, permite ajuste sem ferramentas.

---

### 2.2 Parafuso Prisioneiro (Thumb Screw / Set Screw)

| Aspecto | Detalhe |
|---|---|
| **Complexidade** | Baixa |
| **Custo** | ~R$ 15 |
| **Ajuste** | Contínuo |
| **Pros** | Ajuste contínuo, simples de implementar |
| **Contras** | Pode marcar o tubo interno com o tempo; folga pode surgir com desgaste |

**Como fazer:**
1. Rosquear (ou soldar porca) no tubo externo
2. Parafuso com knob plástico aperta contra o tubo interno
3. Para proteger o tubo interno: aplicar uma chapa de nylon ou disco de borracha na ponta do parafuso

---

### 2.3 Twist-Lock Impresso em 3D

| Aspecto | Detalhe |
|---|---|
| **Complexidade** | Média |
| **Custo** | ~R$ 30 (filamento) |
| **Ajuste** | Contínuo |
| **Pros** | Ajuste rápido, contínuo, sem ferramentas |
| **Contras** | Precisa de impressora 3D; resistência depende do plástico |

**Princípio:** Um mecanismo excêntrico interno (tipo twist-lock de bastão de cortina) que se expande ao girar, travando o tubo interno contra o externo.

**Referência:** Thingiverse "Telescopic Pole Twist-Lock Mechanism" por Polyfoil — https://www.thingiverse.com/thing:4926237

---

### 2.4 Macaco Parafuso (Acme Thread / Screw Jack)

| Aspecto | Detalhe |
|---|---|
| **Complexidade** | Média-Alta |
| **Custo** | ~R$ 50–80 |
| **Ajuste** | Contínuo, fino |
| **Pros** | Ajuste preciso e contínuo, sem folga, auto-travante sob carga |
| **Contras** | Mais trabalho de usinagem; lento para grandes mudanças |

**Princípio:** Rosca trapezoidal (Acme, 29°) usada como macaco. Girar o parafuso eleva ou desce a mesa. Auto-travante por atrito da rosca.

**Implementação simplificada:**
- Parafuso rosca métrica (M12, M16) com porca soldada na base do tubo externo
- Girar o parafuso por baixo ajusta a altura do pé
- Para mesa com 4 colunas: 4 macacos independentes ou 2 por lado ligados por eixo+coringa

---

### 2.5 Gás Lift de Cadeira (Salvado)

| Aspecto | Detalhe |
|---|---|
| **Complexidade** | Média |
| **Custo** | ~R$ 30–60 |
| **Ajuste** | Contínuo, suave |
| **Pros** | Ajuste suave, rápido, barato se recuperado de cadeira velha |
| **Contras** | Curso limitado (~10–15 cm); precisa adaptar ao tubo; carga limitada |

**Implementação:** Remover o cilindro de gás de uma cadeira de escritório velha. Adaptar com buchas para encaixar nos tubos. Cada coluna usa um cilindro.

---

## 3. Comparativo de Mecanismos

| Mecanismo | Custo | Ajuste | Complexidade | Vibração | Velocidade |
|---|---|---|---|---|---|
| Pino + furos | R$ 10 | Discreto (~25 mm) | Baixa | Zero | Média |
| Thumb screw | R$ 15 | Contínuo | Baixa | Baixa | Rápida |
| Twist-lock 3D | R$ 30 | Contínuo | Média | Baixa | Rápida |
| Macaco rosca | R$ 50–80 | Contínuo, fino | Média-Alta | Zero | Lenta |
| Gás lift | R$ 30–60 | Contínuo | Média | Zero | Rápida |

---

## 4. Sugestão Pragmática (Custo-Benefício)

Para a maioria dos cenários:

- **2 colunas telescópicas:** tubo 50x50 (esp 3,75 mm) externo + tubo 40x40 interno
- **Bucha de nylon ou fita UHMW** nas pontas do tubo externo para eliminar folga/vibração
- **Pino quick-release** (tipo bicicleta, com mola/bola): furar o tubo externo de 25 em 25 mm, e furos no interno nas mesmas alturas
- **~6–8 posições** cobrem de sentado a em pé (~95 cm a ~118 cm)

Custo estimado por mesa (2 colunas): ~R$ 80–150 (tubos + pinos + buchas).

---

## Referências

- Alcobra Metals: "Steel Telescoping Square Tubing" — https://alcobrametals.com/telescopic-tubing/steel-telescoping-square-tubing-095/
- Lock Joint Tube: "Steel Telescopic Tubing" — https://www.ljtube.com/tubing/tubing-by-shape/telescopic/
- Thingiverse: "Telescopic Pole Twist-Lock Mechanism" — https://www.thingiverse.com/thing:4926237
- Tools Radar: "Innovative Mechanisms for Adjustable Desk Legs" — https://toolsradar.com/innovative-mechanisms-for-adjustable-desk-legs/
- Fábrica do Projeto: "Tabela de Tubo Industrial Quadrado" — https://www.fabricadoprojeto.com.br/tabelas-de-laminados-trefilados-e-itens-comerciais/tabelas-fapro-tubo-industrial-quadrado/

---

*Para dados ergonômicos (altura do brasileiro, ângulos, tolerâncias), ver [ergonomics.md](ergonomics.md).*

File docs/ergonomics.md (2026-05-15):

# Ergonomics Reference

Practical ergonomic data for designing adjustable workstations. Focuses on the Brazilian population and standing desk use.

---

## Anthropometric Data — Brazilian Population

| Metric | Homem (média) | Mulher (média) | Fonte |
|---|---|---|---|
| Altura | 1,73–1,75 m | 1,60–1,62 m | BBC; Veja; Toda Matéria (estudos 2016–2024) |
| Altura do cotovelo (estimada) | ~109 cm | ~100 cm | ~63% da altura em pé |

O brasileiro está abaixo da média mundial de altura, mas cresceu nas últimas décadas. Para dimensionar uma mesa que sirva a maioria da população (5° ao 95° percentil), considerar:

| Perfil | Altura pessoa | Altura cotovelo (chão) |
|---|---|---|
| Mulher baixa (5° perc.) | ~1,50 m | ~94 cm |
| Mulher média | ~1,60 m | ~100 cm |
| Homem médio | ~1,73 m | ~109 cm |
| Homem alto (95° perc.) | ~1,85 m | ~116 cm |

**Faixa de ajuste necessária:** ~94 cm a ~116 cm (22 cm de curso) para cobrir 90% da população adulta brasileira.

---

## Standing Desk — Height and Angles

### Ângulo do cotovelo

- **Ideal:** 90° com antebraços paralelos ao piso
- **Tolerância aceitável:** 90° a 110° (ligeiramente obtuso é preferível para digitação prolongada — reduz tensão nos punhos e ombros)
- **Ombros devem estar relaxados** — nunca elevados para alcançar a mesa

### Altura da mesa por perfil

| Perfil | Altura pessoa | Altura mesa (chão → superfície) |
|---|---|---|
| Mulher baixa | ~1,50 m | ~94–96 cm |
| Mulher média | ~1,60 m | ~100–102 cm |
| Homem médio | ~1,73 m | ~109–111 cm |
| Homem alto | ~1,85 m | ~116–118 cm |

### Regra prática

Fique em pé, braços relaxados ao lado do corpo, dobre os cotovelos a 90° — a superfície da mesa deve ficar exatamente na altura dos antebraços.

### Monitor

Topo da tela na linha dos olhos. Se usar banqueta, o monitor precisa acompanhar a nova altura.

---

## Banqueta / Leaning Stool para Mesa em Pé

### O que é

Banqueta alta regulável projetada para "semi-pé" (perching) — a pessoa apoia parte do peso na banqueta e parte nas pernas. Também chamada de leaning stool, perch stool, ou standing desk chair.

### Benefícios

- Reduz fadiga nas pernas e costas em sessões longas
- Mantém o tronco mais ereto que sentar completamente
- Encoraja micro-movimentos e ativação do core
- Permite alternância entre pé, semi-pé e sentado ao longo do dia
- Pesquisas indicam que alternar posturas reduz carga spinal e desconforto vs. manter uma posição fixa

### Tipos

- **Wobble stool:** Base arredondada que permite movimentação natural
- **Leaning stool:** Design angulado que apoia sem colapsar a postura
- **Sit-stand chair:** Regulável entre posição sentada e perching

### Cuidados

- A banqueta precisa ser **regulável** — quadril deve ficar ligeiramente acima dos joelhos
- Não serve para usar o dia todo — alternar a cada 30–45 minutos
- Se a mesa não é ajustável, uma banqueta alta pode **piorar** a ergonomia (cotovelos acima de 90° = ombros elevados = tensão)
- A altura do monitor precisa acompanhar a nova postura

### Quando ajuda

- Mesa com altura regulável + banqueta regulável = cenário ideal
- Pessoa mais alta usando mesa fixa baixa: banqueta pode prejudicar se não houver ajuste de mesa
- Pessoa mais baixa usando mesa alta: banqueta pode ser a solução para alcançar a altura correta

### Regras de uso correto

1. Quadril ligeiramente acima dos joelhos
2. Pés apoiados (flat ou leve no chão)
3. Pelve neutra — sem arquear ou encolher
4. Core levemente ativado — "alto e leve", não tenso
5. Alternar frequentemente — não ficar na banqueta mais de 30–45 min seguidos

---

## Referências

- BBC Brasil: "Brasileiro cresce em altura nos últimos cem anos" — https://www.bbc.com/portuguese/geral-36892772
- Veja: "Brasileiro cresceu, mas continua com estatura baixa" — https://veja.abril.com.br/saude/brasileiro-cresceu-mas-continua-com-estatura-baixa/
- Pain Free Start (fisioterapeuta): "Standing Desk Stools & Leaning Chairs" — https://painfreestart.com/standing-desk-stools-and-leaning-chairs-do-they-really-help-a-physiotherapists-perspective/
- Contour Design: "How to Set Up an Ergonomic Standing Desk" — https://www.contourdesign.com/workstations/ergonomic-standing-desk-setup
- Uncaged Ergonomics: "Standing Desk Height Guide" — https://uncagedergonomics.com/blogs/default-blog/standing-desk-height-guide

---

*Para mecanismos construtivos de altura regulável (tubos telescópicos, pinos, travamentos), ver [adjustable-height-mechanisms.md](adjustable-height-mechanisms.md).*

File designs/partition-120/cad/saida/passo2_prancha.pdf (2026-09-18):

FRENTE (1:25), folha central de face | LATERAL (1:25), folhas das pontas de face

### TOPO (1:25), vista de cima

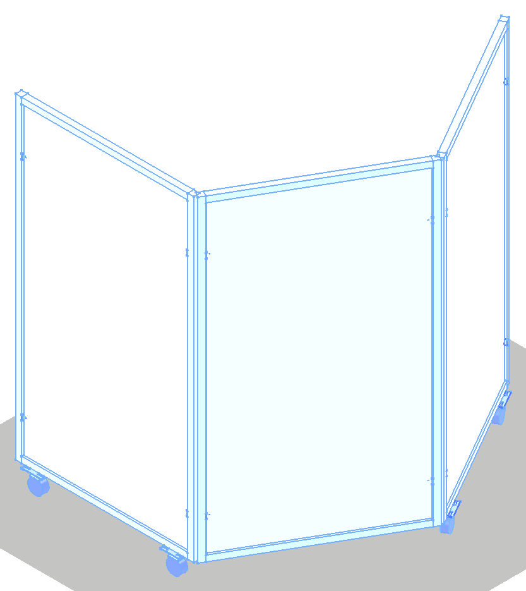
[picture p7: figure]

### COMPENSADO DECORADO (1:20) - 1 por folha

### ISOMETRICA (1:25, mesma escala das vistas)

x = centro dos 4 furos de parafuso (piloto dia 2,5), a 12 mm da borda da placa, nas alturas Z0+200 e Z0+1340

### FIXACAO E MONTAGEM

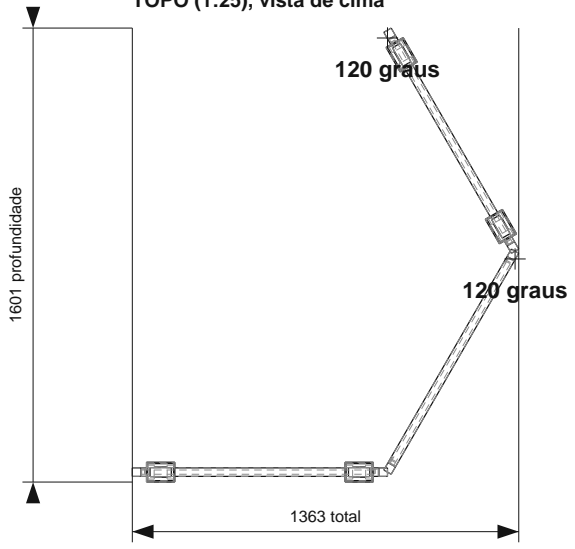
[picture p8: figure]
1363 total; 1601 profundidade; 120 graus

4 cantoneiras 25x25x3 por folha, soldadas de face na face interna dos montantes,
em Z0+200 e Z0+1340 (2 por montante): perna A (22,5) soldada no tubo, perna B (25) deitada sobre a face do compensado, furo dia 4,2 a 15 mm da face interna.
Parafuso de madeira dia 4 x 16 (piloto dia 2,5): atravessa a perna B e entra
13 mm no compensado, com 2 mm de fundo.
ORDEM: 1) soldar as cantoneiras. 2) colar o acabamento na placa (espuma 3 + tecido 1 por face, opcional) e estofar. 3) encaixar a placa na moldura.
4) aparafusar: o parafuso pega a cantoneira, o acabamento e o compensado.
COM acabamento: soldar a cantoneira encostada no painel JA montado (face interna da perna B a 11,5 mm do plano medio) e usar parafuso dia 4 x 20.

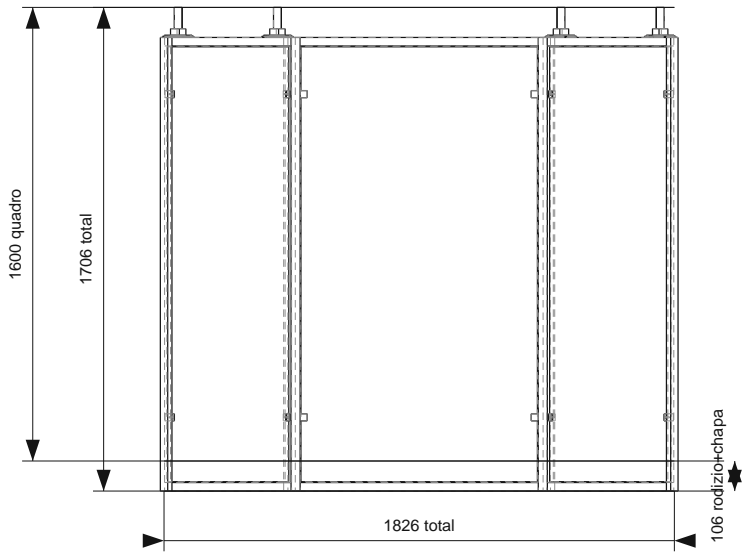
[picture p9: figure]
1826 total; 1706 total; 1600 quadro; 106 rodizio+chapa

1363 total

1706 total

834

1534

### LISTA DE MATERIAL

peca | especificacao medida | qtd
montante 30x30x1,5 1600 mm 6
travessa 30x30x1,5 | 840 mm 6
TOTAL tubo | 14640 mm 12
chapa base 100x70x4 400 mm 4 4 rasgos 25x9 passo 70x40 cantoneira L 25x25x3 perna A 22,5 12 2 por montante, Z0+200 e Z0+1340 compensado decorado 15 834 mm 3 (834 x 1534 mm), 1 por folha
parafuso madeira 4x16 16 mm 12 piloto 2,5; cabeca panela 8
rodizio dia 75 freio 102 mm 4 roda de borracha, placa 91,5x60
acabamento OPCIONAL 3+1 mm - espuma 3 mm e tecido <1 mm nas 2 faces

## Habitat / LaRA-UERJ

### BIOMBO 120 - PASSO 2: PLACA DE COMPENSADO DECORADO

Placa 834 x 1534 x 15 mm fixada por 12 cantoneiras 25x25x3; rodizio dia 75 com freio

Cantoneira: perna A 22,5 soldada de face no montante + perna B deitada no compensado

Fabricado 55.32 kg (tubo 19.652 + placa 34.543 + abas 0.332) | carga/rodizio 13.8 kg
Tombamento 175.0 mm -> 11.07 graus (1b: 179,9 / 11,62) | A3 1o diedro mm | Rev. 04 2026-09-18

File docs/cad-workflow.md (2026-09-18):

# Pipeline de CAD: FreeCAD headless + reportlab

Como este repositório produz prancha cotada para serralheiro, por código, sem GUI.
Implementação de referência: [`scripts/cad_lib.py`](../scripts/cad_lib.py) e
[`designs/partition-120/cad/biombo_passo1.py`](../designs/partition-120/cad/biombo_passo1.py).

```bash
freecadcmd designs/<modulo>/cad/<script>.py
```

---

## Por que FreeCAD e não OpenSCAD

1. **OpenSCAD não exporta STEP nem IGES** (só STL/DXF/SVG). Sem STEP não há troca com
   quem tem CAD — e é o formato que o mundo metal-mecânico usa.
2. `projection()` do OpenSCAD devolve silhueta achatada, sem aresta oculta. O serralheiro
   lê aresta para saber onde solda; o TechDraw faz HLR do sólido real.
3. Cota no FreeCAD sai do modelo. No OpenSCAD você desenha cada cota como geometria 2D.

OpenSCAD só ganha para DXF de peça plana (chapa ou painel cortado a laser/plasma). Se
precisar, use, mas não troque a cadeia principal.

## Visão geral do fluxo

```
tabela de parâmetros (mm)
  -> sólidos FreeCAD (Part.makeBox / makeCylinder / barra orientada)
  -> projeção TechDraw com HLR (visible + hidden)
  -> segmentos 2D e projectPoint
  -> folha A3 em reportlab, em mm reais, com cotas desenhadas à mão
  -> PDF carimbado + DXF + STEP + CSV + relatório JSON
  -> verificações automáticas
```

## API da biblioteca

`scripts/cad_lib.py` expõe:

```python
doc = cl.novo_doc("Nome")
pecas = [cl.caixa(doc, nome, base_xyz, L, W, H),
         cl.barra(doc, nome, p1_xyz, p2_xyz, sec),            # seção centrada no eixo
         cl.caixa_orientada(doc, nome, centro_xy, ang_deg, L, W, H, z_base),
         cl.cilindro(doc, nome, centro_xyz, ang_deg, dia, comp)]   # eixo horizontal
doc.recompute()
med = cl.medir(pecas)          # min/max/centro/volume

prj = cl.Projetor(doc, template="A3")
v = prj.vista(nome, pecas, *cl.DIRECOES["Frente"], med["centro"])
# v -> vis, hid, w, h, loc (bbox local), pp0, alertas

f = cl.Folha("saida/prancha.pdf", "A3")
f.moldura()
f.poe(v, x_mm, y_mm, escala)
f.desenha(); f.rotulo_vista("Frente")
f.cota_h("Frente", pa_xyz, pb_xyz, off_mm, "1440 total")
f.cota_v("Frente", pa_xyz, pb_xyz, -9.0, "100 rodizio")     # off negativo = à direita
f.anotacao("Planta", x, y, z, "120 graus")
f.lista_corte("LISTA DE CORTE", "cabecalho", linhas, x, y)
f.carimbo([(texto, tamanho, negrito), ...])
problemas = f.salva()          # [] = ok
```

`cl.DIRECOES` traz Frente/Planta/Lateral/Posterior/Iso já na convenção de 1º diedro.

---

## Pitfalls do FreeCAD 1.1 headless

Todos verificados na prática. Nenhum deles dá erro útil — dão desenho errado silencioso.

### O que existe e o que não existe

```
Existe:     writeDXFPage, writeDXFView, projectToDXF, projectToSVG, exportSVGEdges,
            DrawViewDimension, v.projectPoint(), v.getVisibleEdges(), v.getHiddenEdges()
Não existe: writePageAsPdf  ->  o PDF tem que sair do reportlab
Não existe: v.ShowHiddenLines  ->  quem manda é v.HardHidden (padrão False)
```

`projectToDXF`, `projectToSVG`, `exportSVGEdges` e `viewPartAsDxf` **não** recebem a
vista nem a página — recebem `Part.Shape`, ou um argumento só. A assinatura não bate com
o nome. Use `writeDXFPage(page, arquivo)`.

### XDirection é obrigatório e tem que ser perpendicular

Se `XDirection` não for perpendicular a `Direction`, a vista falha com
`failed to create projection CS` e sai vazia (o aviso aparece uma vez por recompute).

```
direita = XDirection normalizado
cima    = Direction x XDirection
```

`Direction` é o vetor do **objeto para o observador**. Conjunto de 1º diedro (ABNT):

| Vista | Direction | XDirection | Resultado |
|---|---|---|---|
| Frente | (0,-1,0) | (1,0,0) | direita=+X, cima=+Z |
| Planta | (0,0,-1) | (1,0,0) | direita=+X, cima=-Y (fica abaixo) |
| Lateral | (1,0,0) | (0,1,0) | direita=+Y, cima=+Z (fica à direita) |

Os dois `-1` são o que produz 1º diedro. Trocar o sinal espelha ou inverte a vista **sem
nenhum erro**. Audite sempre:

```python
pp0 = v.projectPoint(centro_do_bbox_do_modelo)
sig = {k: (round((v.projectPoint(Vector(*p)).x - pp0.x)/100),
           round((v.projectPoint(Vector(*p)).y - pp0.y)/100))
       for k, p in (("x",(100,0,0)), ("y",(0,100,0)), ("z",(0,0,100)))}
# Frente  x:(1,0)  y:(0,0)   z:(0,1)
# Planta  x:(1,0)  y:(0,-1)  z:(0,0)
# Lateral x:(0,0)  y:(1,0)   z:(0,1)
```

### Dois referenciais de coordenada

- `getVisibleEdges()` / `getHiddenEdges()` devolvem 2D **centrado no conteúdo** da vista
  (bbox simétrico em torno de 0), em mm reais — `Scale` não afeta.
- `v.projectPoint(p)` devolve **absoluto** `(p·direita, p·cima)`, sem centrar.

Para desenhar misturando os dois, use o offset `pp0` (já embutido em `Folha.para_folha`):

```
folha_x = X0 + (local_x - local_xmin) * escala                     # dos edges
folha_x = X0 + (pp(p).x - pp0.x - local_xmin) * escala             # do projectPoint
```

**Vista oblíqua precisa de `centrar_no_conteudo=True`.** A conversão acima pressupõe que o
centro do conteúdo projetado seja a projeção do centro do bbox 3D do modelo. Isso vale para
vista alinhada aos eixos (frente/planta/lateral padrão); numa vista perpendicular a uma folha
a 60°, não vale — o conteúdo fica descentrado em relação à projeção do bbox e **toda cota
ancorada em ponto do modelo cai fora da caixa da vista** (o `verificar()` acusa, mas depois de
você já ter desenhado tudo). Passe o parâmetro:

```python
VS["Frente"] = prj.vista("Frente", pecas, direction, xdirection, med["centro"],
                         centrar_no_conteudo=True)
```

Aí o `pp0` é medido amostrando vértices e arestas curvas do modelo, e `para_folha` volta a
fechar. Sem o parâmetro, o comportamento antigo é preservado (é o que mantém o passo 1 do
biombo reproduzível byte a byte).

A vista também é **centrada no próprio conteúdo** na página. Posicionar por canto erra;
ancore sempre pelo bbox do conteúdo.

### Arestas ocultas: ligar explicitamente

```python
v.HardHidden = True      # arestas de sólido
v.SmoothHidden = True    # tangência de cilindro (rodízio, tubo redondo)
v.SeamHidden = False     # costura do cilindro: linha suja, deixe desligada
```

Sem isso `getHiddenEdges()` volta `[]` e você conclui que não há nada escondido.

### writeDXFPage ignora mudanças recentes

Na **mesma sessão**, depois de setar `v.Scale` / `v.X` / `v.Y`, `writeDXFPage` exporta a
geometria em escala 1. Testados e inúteis: `doc.recompute()`, `v.touch()`,
`pg.recompute()`, ler `v.getVisibleEdges()`. **Só resolve salvar e reabrir:**

```python
doc.saveAs(fcstd); App.closeDocument(doc.Name)
doc2 = App.openDocument(fcstd)
pg2 = [o for o in doc2.Objects if o.TypeId == "TechDraw::DrawPage"][0]
TechDraw.writeDXFPage(pg2, dxf)
```

`writeDXFPage` exporta **só as vistas**. Moldura, carimbo e as cotas que você desenhou no
reportlab não vão para o DXF. Se o DXF precisar carregar cota, crie objetos
`TechDraw::DrawViewDimension` (saem como entidade DIMENSION). Confira `$INSUNITS` = 4 (mm).
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

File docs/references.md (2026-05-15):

# References

Collected visual references, open-source projects, books, videos, and institutional examples.

---

## Visual Inspiration

### Modular / Adaptive Environments

- https://images.adsttc.com/media/images/67f3/b8b1/bb96/c901/8954/561c/newsletter/more-than-furniture-pods-as-an-adaptation-strategy-in-offices_1.jpg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

**Common elements:** Lightweight movable partitions, hybrid spaces (meeting + focus + collaboration), independent pods, integrated vegetation, easily reconfigurable layouts.

### Furniture and Elements

- https://i.pinimg.com/originals/33/f3/fd/33f3fde6c46884a3d01e471f1ef0234c.jpg
- https://cdn.shopify.com/s/files/1/0832/9415/files/1_f4c45306-6c77-4f09-8081-105c9ef9bf70_2048x2048.jpg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

**Elements shown:** Modular sofas with planters, semi-private niches, mobile acoustic booths, stackable independent modules, expandable/contractible stations.
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

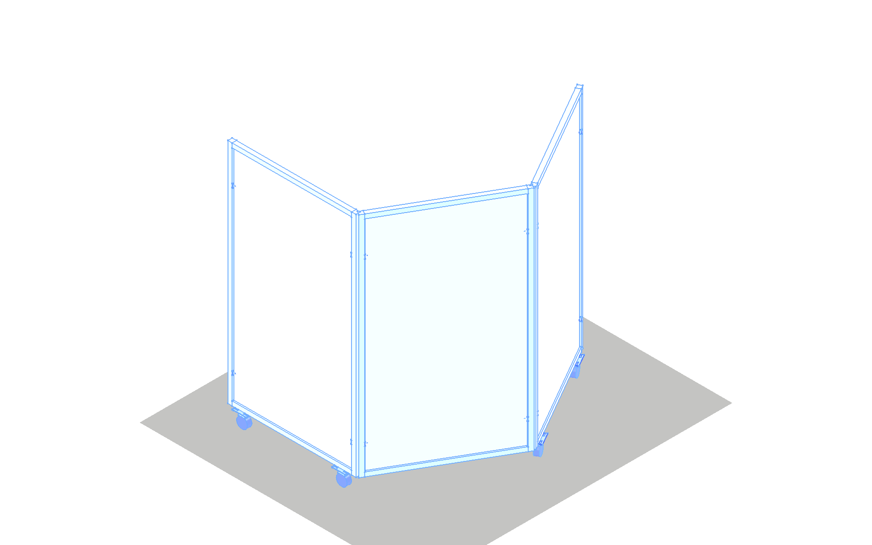
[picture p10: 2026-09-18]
designs/partition-120/cad/saida/passo2_render_iso.png

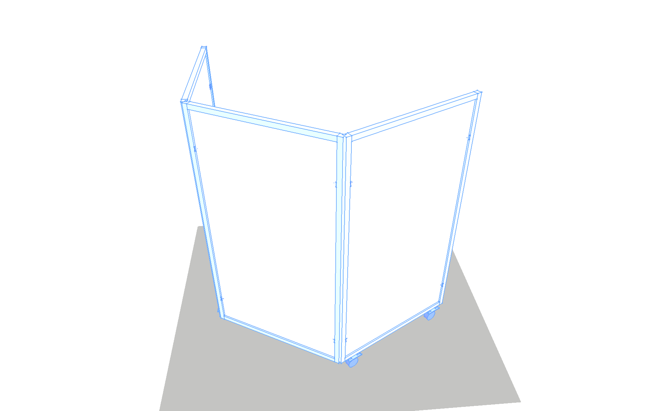
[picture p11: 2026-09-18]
designs/partition-120/cad/saida/passo2_render_persp.png

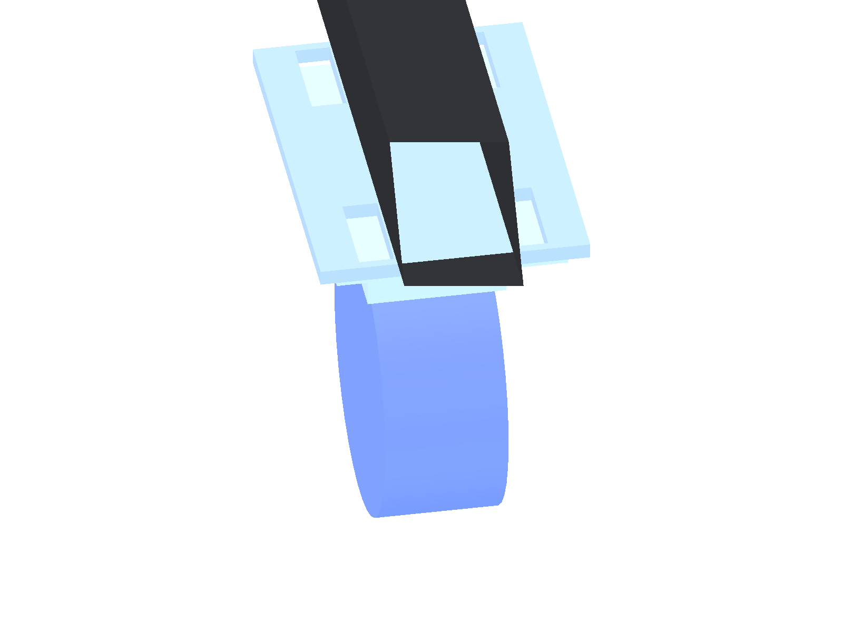
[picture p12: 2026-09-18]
designs/partition-120/cad/saida/passo1b_render_close.png

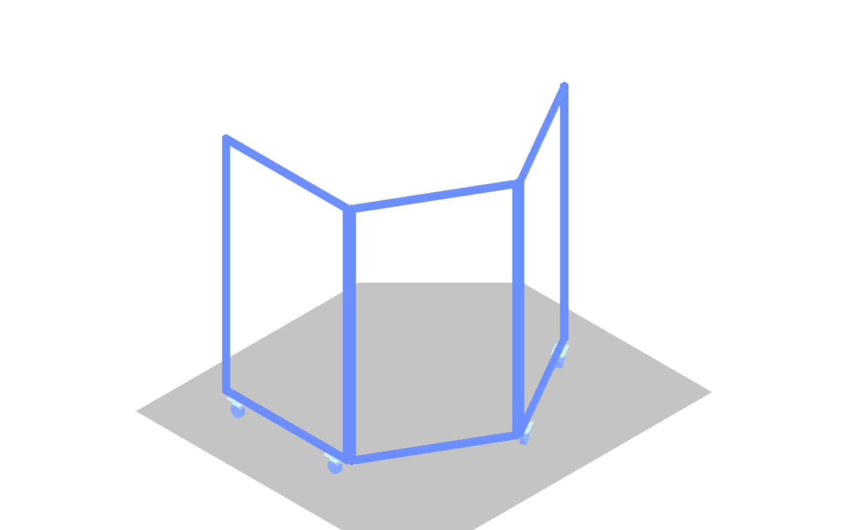
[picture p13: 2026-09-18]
designs/partition-120/cad/saida/passo1b_render_iso.png

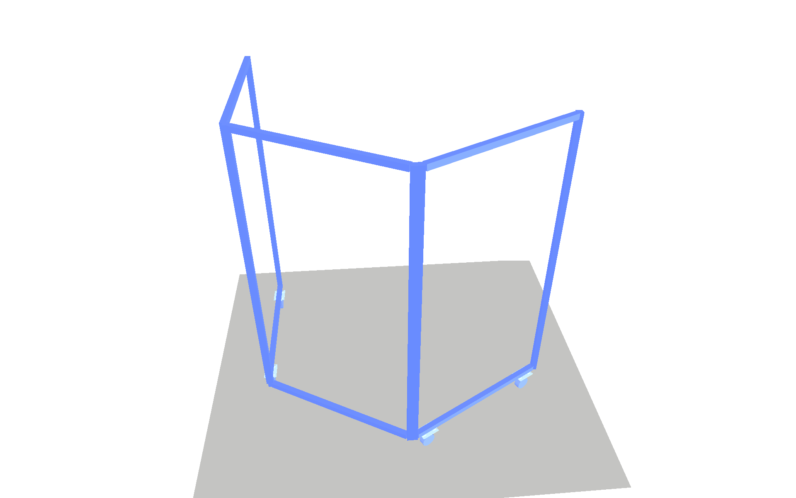
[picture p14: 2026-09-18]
designs/partition-120/cad/saida/passo1b_render_persp.png

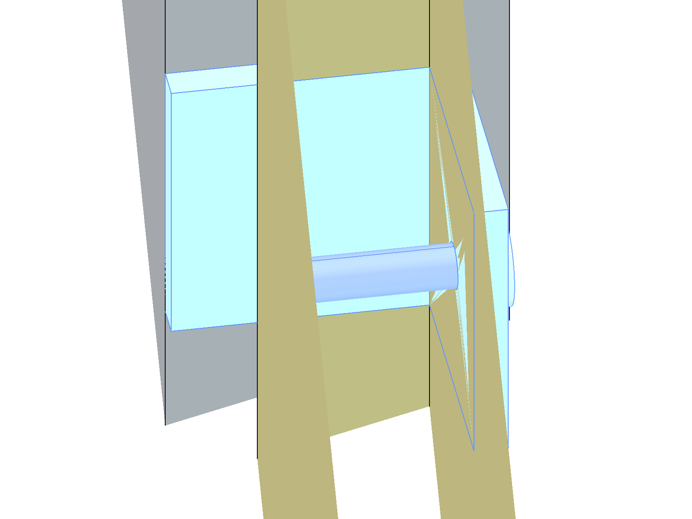
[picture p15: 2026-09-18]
designs/partition-120/cad/saida/passo2_render_close.png

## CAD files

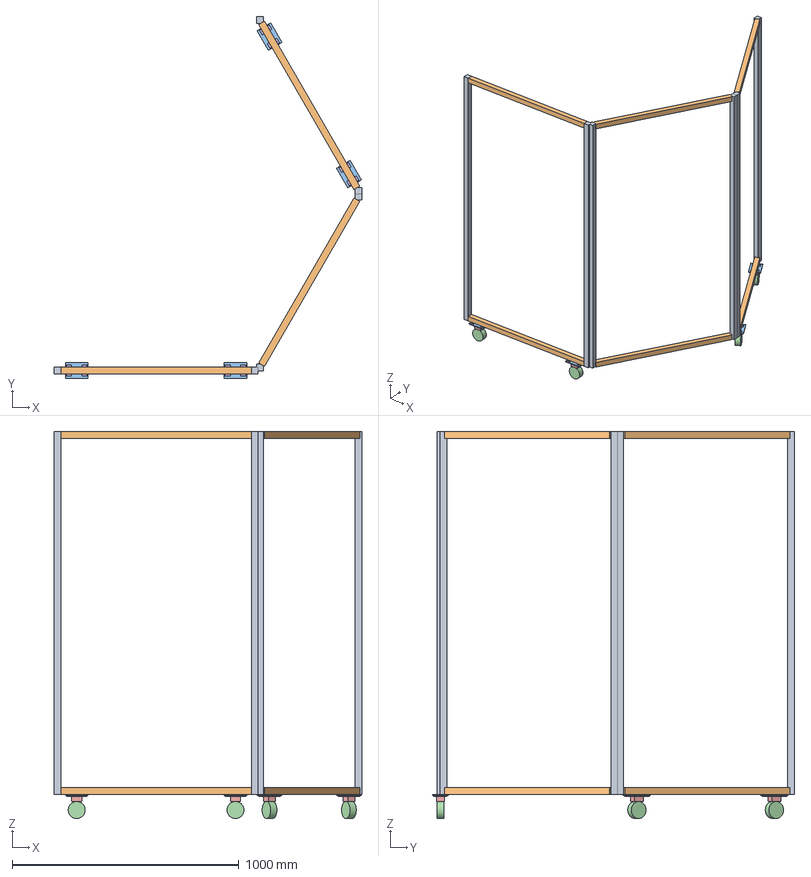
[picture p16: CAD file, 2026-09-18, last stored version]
designs/partition-120/cad/saida/passo1b_biombo.step
1357.5 x 1595.9 x 1705.9 mm
folha1_mont_a
folha1_mont_b
folha1_trav_inf
folha1_trav_sup
folha1_a_chapa
folha1_a_roda
folha1_a_garfo
folha1_a_placa
folha1_b_chapa
folha1_b_roda
folha1_b_garfo
folha1_b_placa
folha2_mont_a
folha2_mont_b
folha2_trav_inf
folha2_trav_sup
folha3_mont_a
folha3_mont_b
folha3_trav_inf
folha3_trav_sup
folha3_a_chapa
folha3_a_roda
folha3_a_garfo
folha3_a_placa
folha3_b_chapa
folha3_b_roda
folha3_b_garfo
folha3_b_placa

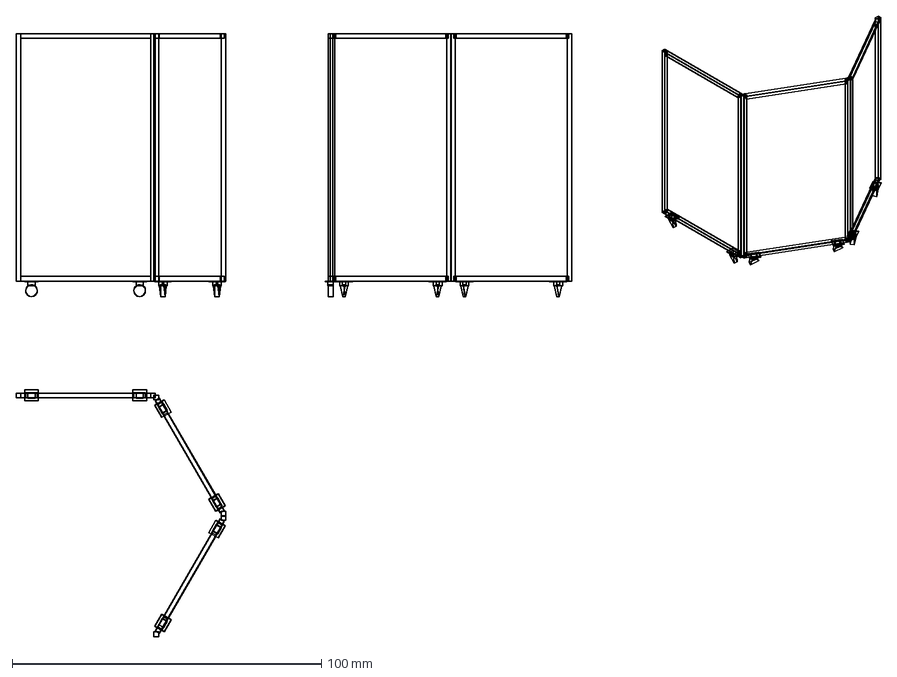
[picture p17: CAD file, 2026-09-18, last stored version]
designs/partition-120/cad/saida/passo1_prancha.dxf
279.8 x 200.6 mm

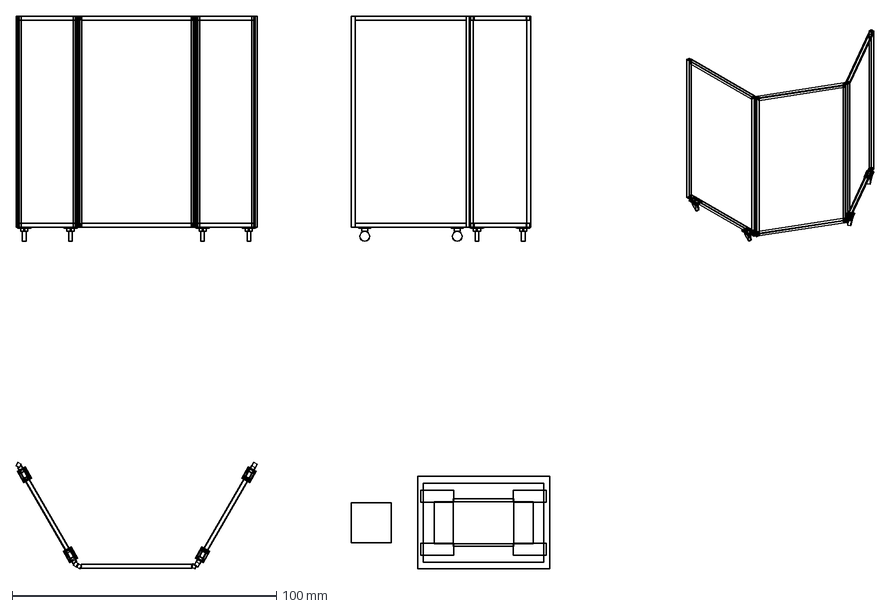
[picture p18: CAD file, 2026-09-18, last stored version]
designs/partition-120/cad/saida/passo1b_prancha.dxf
324.8 x 209.3 mm

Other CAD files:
designs/partition-120/cad/saida/passo1_biombo.step

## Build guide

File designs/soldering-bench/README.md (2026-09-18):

# Soldering Bench

Mobile standing bench for PCB soldering, rework, and electronics assembly.

---

## Brief

A self-contained workbench for soldering and electronics rework that can be moved around the lab. Designed for standing work with integrated tool storage via a perforated pegboard panel.

### Requirements

- **Standing height work surface** — Optimized for precision soldering while standing (approximately elbow height)
- **Integrated pegboard panel** — Perforated panel attached to the bench for hanging tools (soldering iron, hot air station, probes, tweezers, wire cutters)
- **Soldering iron holder** — Fixed mount on the bench or pegboard for soldering iron, accessible without reaching
- **Hot air station mount** — Space for hot air rework station on the bench surface
- **Mobile (casters)** — Casters with brakes for repositioning. Bench must be stable when brakes are engaged
- **ESD-safe** — Grounded work surface (ESD mat) and grounding point for wrist strap

### Design Options (Not Decided)

1. **Aluminum extrusion frame (V-slot 4040 or 2040)** — Modular, reconfigurable, clean industrial look. Pegboard mounts with T-slot brackets. Pros: infinitely adjustable. Cons: cost, visible hardware.
2. **Plywood + steel frame** — Birch plywood panels on welded or bolted steel frame. Warmer aesthetic. Pros: cheaper, quieter acoustically. Cons: harder to modify once built.
3. **All-plywood CNC-cut** — Flat-pack design cut on the lab's CNC. Inspired by OpenStructures grid. Pros: the lab builds its own bench. Cons: structural limitations of plywood-only.

### Dimensions (TBD)

- Width: ~100–120 cm
- Depth: ~60–80 cm
- Height: ~95–105 cm (standing work)
- Pegboard height: ~40–60 cm above work surface

### Equipment Integration

| Equipment | Mounting | Notes |
|---|---|---|
| Soldering iron | Pegboard mount or bench bracket | Within arm's reach, tip holder nearby |
| Hot air station | Bench surface, right side | Needs power outlet |
| Multimeter | Pegboard hook or small shelf | Frequently used, must be accessible |
| Oscilloscope | Bench surface (if needed) | May live on shared cart instead |
| Flux, solder, tips | Small bins on pegboard | Consumables — labeled, restocked |
| ESD mat | Full work surface | Grounded to bench frame |
| Fume extractor | Bench-mounted or overhead | Important for solder fumes |
| Power strip | Under-bench mount | Multiple outlets for iron + hot air + lamp |
| Task light | Pegboard or overhead arm | Diffused, adjustable, no shadow on work |

### Reference Images

### Concept Render

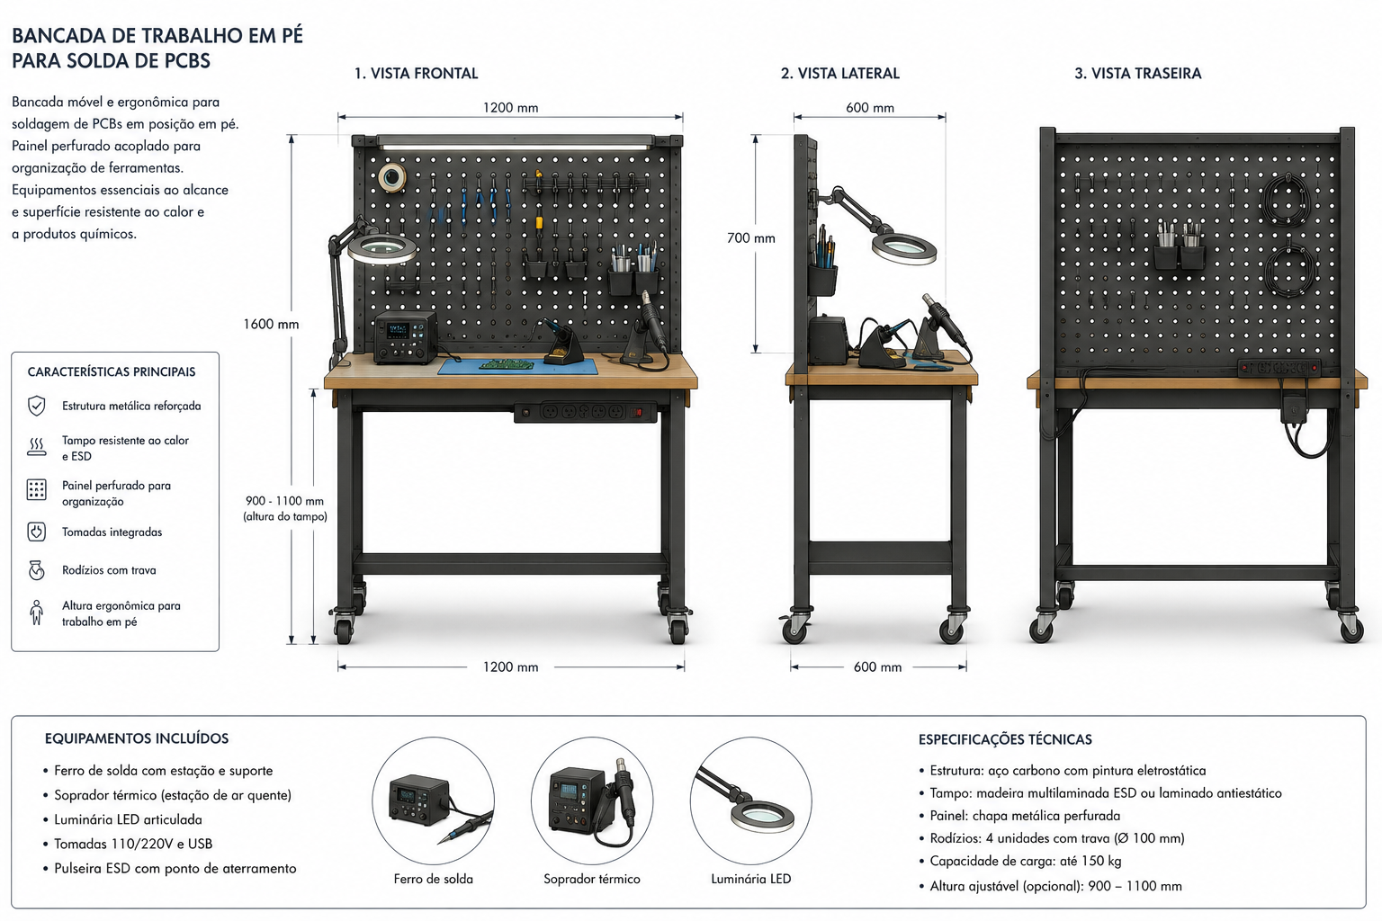
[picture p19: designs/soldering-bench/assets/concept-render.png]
Soldering bench concept


*Mobile standing bench with pegboard panel, soldering iron, hot air station, and casters.*

### Principles Being Evaluated

- [Postural variation](../../docs/design-principles-catalog.md#postural-variation) — Standing-only for this bench
- [Everything on casters](../../docs/design-principles-catalog.md#everything-on-casters) — Mobile by requirement
- [Vertical surfaces as mental extension](../../docs/design-principles-catalog.md#walls-as-mental-extension) — Pegboard as tool display + shadow board
- [Task differentiation](../../docs/concepts.md#1-robert-propst--the-office-a-facility-based-on-change-1968) — This bench is only for soldering/rework, not general workspace

### Open Questions

- Cable management for soldering iron, hot air, and lamp when bench is mobile
- Fume extraction: integrated or separate portable unit?
- Storage underneath: open shelf, drawer, or closed cabinet?
- Weight budget: how heavy can the loaded bench be before casters become impractical?

---

## Files

| Path | Description |
|---|---|
| `cad/` | CAD files (.step, .FCStd) — to be added |
| `assets/` | Imagens de referência e renders |

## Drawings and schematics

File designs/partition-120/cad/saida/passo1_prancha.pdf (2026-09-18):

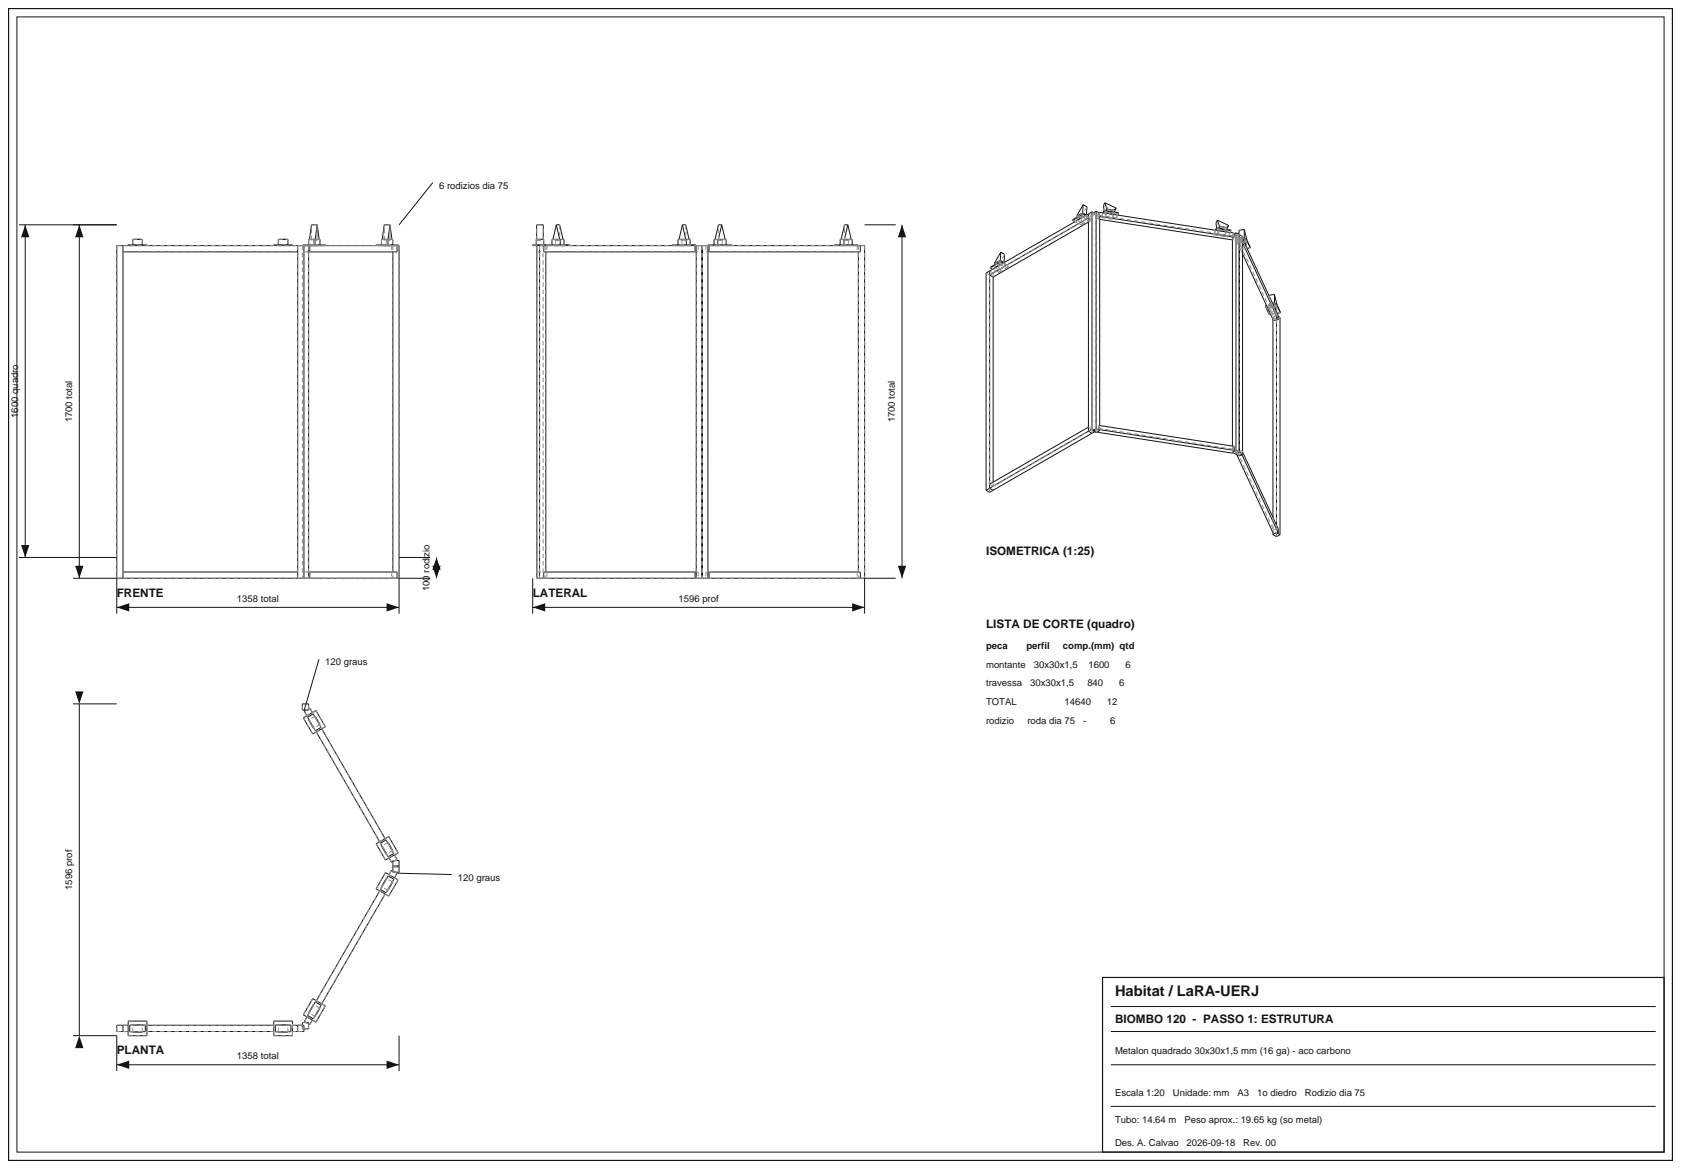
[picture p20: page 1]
PLANTA; FRENTE; LATERAL; ISOMETRICA (1:25); 1358 total; 1700 total; 1600 quadro; 100 rodizio; 6 rodizios dia 75; 1596 prof; 120 graus; peca; perfil comp.(mm) qtd; montante 30x30x1,5 1600; travessa 30x30x1,5 840; TOTAL; rodizio roda dia 75 -

LISTA DE CORTE (quadro)

Habitat / LaRA-UERJ

BIOMBO 120 - PASSO 1: ESTRUTURA

Metalon quadrado 30x30x1,5 mm (16 ga) - aco carbono

Escala 1:20 Unidade: mm A3 1o diedro Rodizio dia 75

Tubo: 14.64 m Peso aprox.: 19.65 kg (so metal)

Des. A. Calvao 2026-09-18 Rev. 00

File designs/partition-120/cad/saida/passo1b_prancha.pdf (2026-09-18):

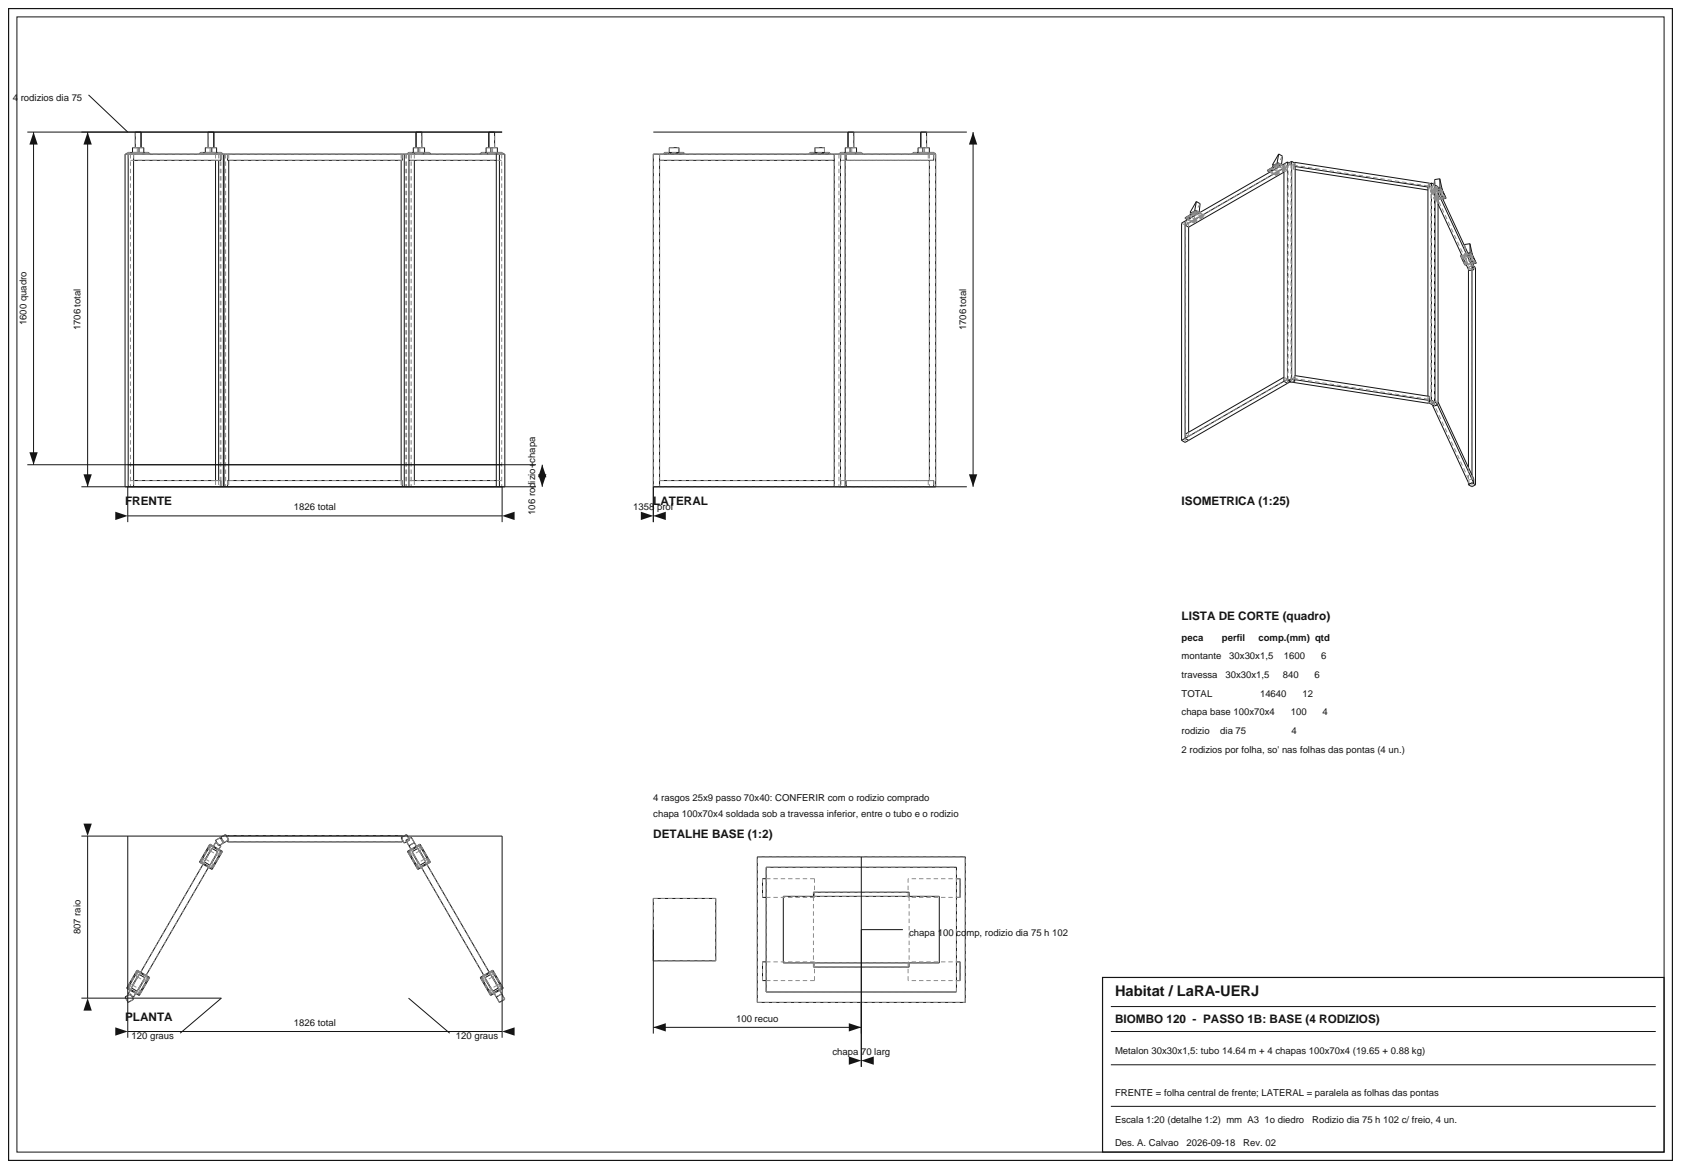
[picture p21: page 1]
PLANTA; FRENTE; LATERAL; ISOMETRICA (1:25); 1826 total; 1706 total; 1600 quadro; 106 rodizio+chapa; 4 rodizios dia 75; 1358 prof; 807 raio; 120 graus; 100 recuo; chapa 70 larg; peca; perfil comp.(mm) qtd; montante 30x30x1,5 1600; travessa 30x30x1,5 840; TOTAL; chapa base 100x70x4; rodizio dia 75

LISTA DE CORTE (quadro)

2 rodizios por folha, so' nas folhas das pontas (4 un.)

4 rasgos 25x9 passo 70x40: CONFERIR com o rodizio comprado
chapa 100x70x4 soldada sob a travessa inferior, entre o tubo e o rodizio
DETALHE BASE (1:2)

chapa 100 comp, rodizio dia 75 h 102

Habitat / LaRA-UERJ

BIOMBO 120 - PASSO 1B: BASE (4 RODIZIOS)

Metalon 30x30x1,5: tubo 14.64 m + 4 chapas 100x70x4 (19.65 + 0.88 kg)

FRENTE = folha central de frente; LATERAL = paralela as folhas das pontas

Escala 1:20 (detalhe 1:2) mm A3 1o diedro Rodizio dia 75 h 102 c/ freio, 4 un.

Des. A. Calvao 2026-09-18 Rev. 02

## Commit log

2026-05-15 Add design principles catalog
    Reference catalog of principles from multiple sources: spatial
    geometry (120°, organic, universal grid), ergonomics, vertical
    surfaces, privacy, adaptability, 5S methodology, materials.
2026-05-15 Add layout ideas and LaRA 7x7m floor plan SVG
    Spatial organization options for the lab including activity-based
    zoning with noise gradient, dual-door circulation flow, and
    robot arena at center.
2026-05-15 Add soldering bench brief and concept render
    Mobile standing bench for PCB soldering with pegboard, ESD,
    soldering iron, hot air station, and casters. Includes
    requirements, design options, equipment integration plan.
2026-05-15 Add workstation 120 brief and concept render
    Computer station with 120° angle, pegboard-mounted monitor,
    whiteboard panel, and casters. Applies Propst's 120° principle.
2026-05-15 Add ergonomics data, partition 120, and focus pod briefs
    Add anthropometric data for Brazilian population, standing desk height
    guidelines, telescoping tube combos and DIY locking mechanisms for
    adjustable height desks. Add Partition 120° (3-panel folding screen
    with acoustic panels) and Focus Pod (mobile semi-enclosed microenvironment
    with retractable L-desk and lounge chair) as new active projects.
2026-09-18 Add agent conventions, CAD workflow doc and FreeCAD ignores
    - AGENTS.md: house rules, checkpoint method, module status table
    - docs/cad-workflow.md: the headless pipeline (FreeCAD + reportlab) and its pitfalls
    - .gitignore: FreeCAD artifacts (*.FCStd, *.FCBak) and __pycache__
2026-09-18 Add headless CAD helpers: drawing library, print auditor, 3D renderer
    - cad_lib.py: solids, TechDraw HLR projection, A3 sheet with hand-drawn dimensions
    (opt-in `centrar_no_conteudo` for oblique views)
    - auditar_prancha.py: ink-density audit of a generated sheet (blank view, overflow
    outside the frame, areas that must stay empty)
    - render_3d.py: 3D PNG renders through the FreeCAD GUI under xvfb
2026-09-18 Add partition-120 CAD: metal frame (step 1) and base (step 1b)
    - step 1: 30x30x1.5 frame, three 900x1600 leaves at 120 deg
    - step 1b: 4 commercial casters (75 mm wheel, 102 mm high, 70 kg) on the outer leaves
    only, 100x70x4 plate welded under the bottom rail with oblong slots
    - artifacts: A3 sheet (PDF/DXF), STEP, cut list, JSON report with measured numbers
    - renders: isometric, perspective and base close-up in PNG
    - front view is the middle leaf; lateral view is parallel to the outer leaves
    [passo1_biombo.step, passo1_lista_corte.csv, passo1_prancha.dxf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]
2026-09-18 Point the repo README at the CAD workflow and fix relative doc links
    The module briefs linked ../docs/... from inside designs/<module>/, one level short.
2026-09-18 Document the 3D render step and list the render artifacts
    - cad-workflow.md: how to render PNG through the FreeCAD GUI under xvfb, with the
    four pitfalls (Std_Quit does not exit, orient before fitting, fit by selection,
    hide the floor on close-ups) and the log-file note
    - partition-120/cad/README.md: render command and the three PNGs in the file table
2026-09-18 Stop versioning DXF and STEP: regenerate them with the CAD scripts
    They come out of running the module's .py, so they do not belong in the repo.
    Kept: A3 sheet (PDF), cut list (CSV), JSON report and the 3D renders.
    .gitignore now covers *.dxf and *.step; the files stay on disk.
    [passo1_biombo.step, passo1_prancha.dxf, passo1b_biombo.step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]
2026-09-18 Add partition-120 CAD step 2: decorated plywood panel and its fixing
    Panel: 15 mm plywood, 834 x 1534, 3 mm off the frame all around, centred on the
    tube depth. Fixing: 12 L-brackets, 25 x 25 x 3 plate, leg A (22.5 mm) face-welded
    on the inner face of the post, leg B lying on the panel, 4 wood screws D4 x 16
    (pilot D2.5) per leaf at Z0+200 and Z0+1340. Foam and fabric stay optional
    (3 + 1 mm per face) and are NOT modelled, as decided on 2026-09-18: the sheet
    shows the decorated plywood only.
    Measured on the built solids (saida/passo2_relatorio.json):
    67 solids | 55.32 kg fabricated | panel 11.51 kg per leaf
    13.8 kg per caster (limit 70) | CG z 894.7 mm
    tip margin 175.0 mm -> 11.07 deg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
    [passo2_lista_compras.csv, passo2_lista_corte.csv]
2026-09-18 Close partition-120 CAD step 2 in the docs: panel, fixing and measurements
    - cad/README.md: step 2 parameter table (plywood 834 x 1534 x 15 mm, 3 mm clearance to
    the tube, 12 L-brackets 25 x 25 x 3 mm with leg A face-welded on the inner face of the
    post and leg B lying on the panel, wood screw D4 x 16 and pilot D2.5), why the fixing
    has that shape (the screw is only reachable along the panel normal), the fabrication
    order (weld the brackets, screw the bare panel, then foam and fabric if they exist),
    the measured table and the two-band sheet layout.
    - designs/partition-120/README.md: panel thickness settled as 15 mm plywood, attachment
    row, stability and weight questions closed wi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
2026-09-18 Update the AGENTS.md state table: partition-120 step 2 approved
    partition-120 now reads steps 1, 1b and 2 (approved: decorated plywood panel
    834 x 1534 x 15 mm, 12 L-brackets 25 x 25 x 3 mm face-welded on the inner face of the
    posts, wood screw D4 x 16; the foam and fabric finish stayed optional and is not
    modelled). Next step: the hinge at the 120 deg joint, where the neighbouring posts
    overlap 207.8 cm3, and the base plate hole spacing checked against the purchased caster
    -- plus deciding the panel finish first.
